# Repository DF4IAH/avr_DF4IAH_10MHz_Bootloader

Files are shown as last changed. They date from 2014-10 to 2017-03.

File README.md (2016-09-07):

# avr_DF4IAH_Bootloader

## GPS disciplined 10 MHz reference oscillator based on a (VC)TCXO
The project name for this device is __10 MHz-Ref.-Osc. V2.x__

That board is attached at the USB bus and receives power and does communication over it.
An optional LCD module can be connected to the I²C compatible bus for a stand-alone operation.

The author is Ulrich Habel (DF4IAH) with the idea having a low-cost and low-power device for a module to generate a 10 MHz signal at 3.3V TTL, that is adjusted to the GPS/Glonass satellite clock system. By this the local clock is kept in its boundaries to satisfy the long-term stability of the GPS/Glonass system. The negative aspect on it (I want to inform, also) with the use of a low power consuming VC-TCXO is, that the short-term variance is much higher than the variance of the devices using a temperature controlled oscillator like a rubidium lightwave controlled one.

### Contents of this repository
- __AVR ATmega 328P__: MPU containing a bootloader for programming the firmware itself via the USB interface by emulating an USBasp device 

- __Lattice LC4032V__: CPLD for containing a phase detection unit - source and binary

- __Eagle drawings__: oscillator and LCD - the schematics and boards for all variants of V2.x

### Additional information
The idea behind that project was to craft a local oscillator being in phase of the GPS clock system.
The device shall have a frequency and phase locked loop.
When the local frequency is trimmed to be equal to the reference GPS clock the phase locked loop gets in place of the frequency control.
Whenever the phase gets out of the secured boundaries, the system switches back to the frequency correction mode.
Due to its nature the device has to keep itself earnestly in the secured boundaries.
Only then the high quality stability of the GPS clock system can be delivered to the user.
For this reason when the local clock gets more out of balance and to one of its boundaries, a phase correction impulse is added to the local system to find the balance, again.
When still running a longer time this pulses are fine grained and the performance is very well for the user.
On the other hand when the GPS signals are poor, the almanac data old or the temperature variance at the VC-TCXO increasing, that local error-signal has to be corrected sometimes with sharp corrections.
So be warned to keep the device running in an air-locked container and a good GPS antenna position is a __must__ to get good results.

There are three different kinds of GPS units used by this project.
Each of them are utilizing the __MediaTek MT3333__ chipset, but each of the manufacturer is running its own configuration on it.
By this, some minor differences occur.
All of this GPS devices are able to track on GPS (western satellites) and Glonass/BeiDou (eastern satellites) signals.
Later at the works the author found out that the parallel processing of GPS and Glonass can result to interrupted functionality.
With NMEA programming the GPS device receives the command to ignore the Glonass signals but not all of them do honor that and start up tracking of all received signals.
The only work-around for this is to use a more selective GPS-antenna that filters out the Glonass signals away from the single GPS frequency.

The author has his reference clocks running for month without any problems, the firmware is stable - __use on your own risk, only!__

If you find this project nice you are welcomed to clone from it and run your optimizations or having a start point for a fresh project.

Any new modifications may result to harm this behavior.
Make your own decisions, be warned.

### Credits
I like to thank these following programmers and groups:

- __VUSB__ This code helped me to have USB communication on an ATmega, that does not support USB communication on its own.
All is done by interrupt software, many parts are assembly language based code.
Due to this nature all code in the bootloader as well as the firmware are very sensitive to changes on the code.
Only a very short interrupt time is allowed for the firmware avoiding the USB communication to fade out.
Find more about it: https://www.obdev.at/products/vusb/index.html

- __Wouter van Ooijen__ That person has reserved a valid USB address to be used by the community.
I like to thank him, that I am a part of this open source development community.

- __USBasp__ The base idea of the circuit is a reflection of this AVR programmer device.
The clou of it, it can communicate at the USB bus by itself: http://www.fischl.de/usbasp/

- __avrdude__ The bootloader code of avrdude gave ideas how to set-up a USB communication server.
The avrdude software can be found there: http://www.nongnu.org/avrdude/

- __HF-Messzwerg__ When the author got in contact with the team of this device, he started to learn about SMD soldering and USB communication in relation with an ATmega.
Communication is done with the help of an USB/serial converter.
More about that project can be found there: http://ukw-tagung.org/2016/preistraeger-2/

I wish you a nice experience with this product.
Fell free and enjoy it.

Cheers

Ulrich Habel  (DF4IAH)

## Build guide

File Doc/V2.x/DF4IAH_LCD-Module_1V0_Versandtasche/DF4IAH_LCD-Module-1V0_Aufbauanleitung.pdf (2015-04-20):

Aubauanleitung
DF4IAH LCD-Module V1.0

DF4IAH, Ulrich Habel

2015-04-18

Received | ; | accepted

– 2 –

### 1. Funktionsweise der Schaltung

Von Conrad und anderen Elektronik-Lieferanten sind LCD-Module erhältlich, die zwei

Textzeilen zu je 16 Zeichen bieten. Sie sind für elektronische Anwendungen sehr attraktiv.

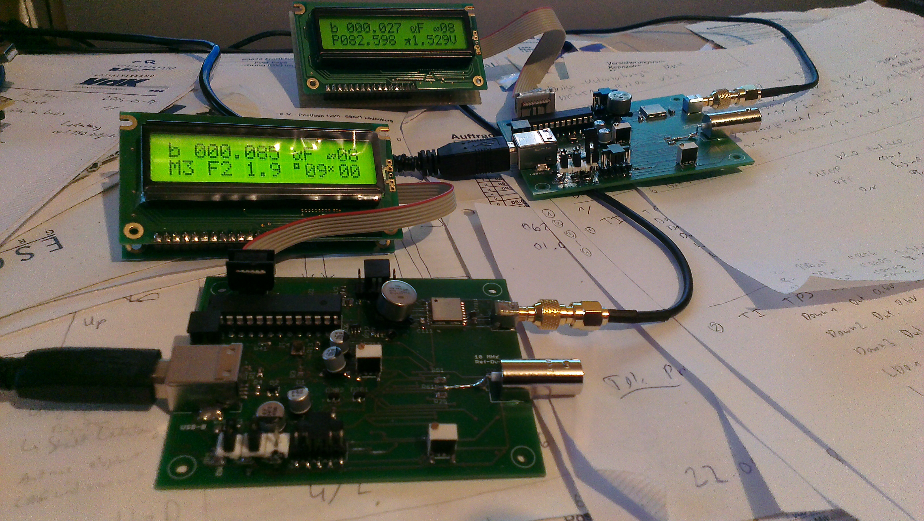
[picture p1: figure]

Fig. 1.— 2x16 LCD-Module in Betrieb

Angeschlossen werden diese über eine Parallelschnittstelle, die bereits eine Vielzahl

von freien I/O-Kanälen eines anzuschließenden µControllers belegen würden. Auf der

anderen Seite bieten solche µController meist auch eine I²C-Schnittstelle an. Die vorliegen-

de Schaltung setzt zwischen einem I²C-Bus und den parallelen Signalen am LCD-Module um.

– 3 –

Hier zunächst der Schaltplan:

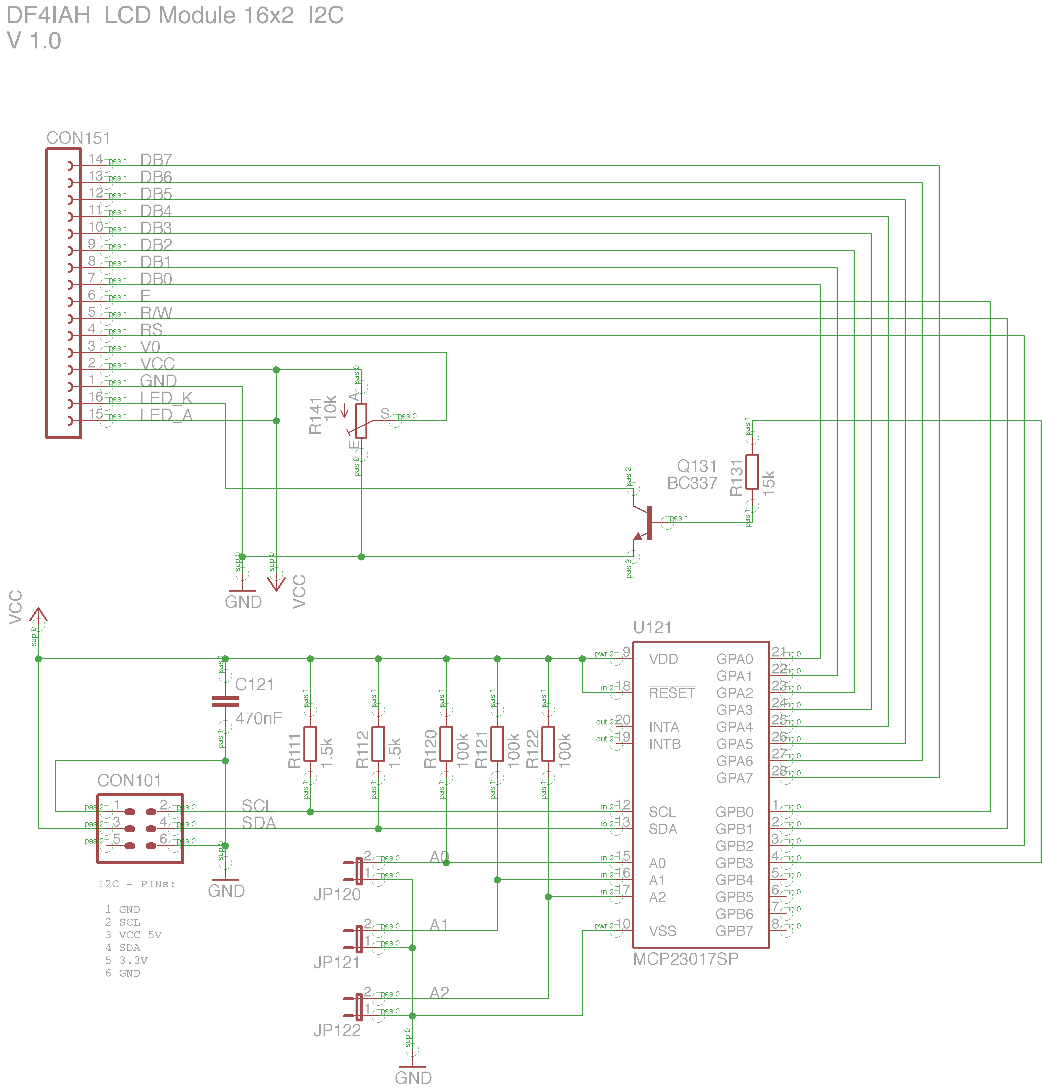
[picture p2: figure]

Fig. 2.— Schaltplan

– 4 –

Über den Steckkontakt CON101 wird die Betriebsspannung von 5.0 V zugeführt. Die

3.3 V wird nicht benötigt, sie ist aus Kompatibilitätsgründen nur aufgeführt. Der I²C-Bus

enthält neben dem obligatorischen Masse-Signal die beiden Signale SCL (Clock) und SDA

(Datentransport). Der I²C-Bus wird hier terminiert. Sollte bereits eine Bus-Terminierung

vorhanden sein, dann sollen die beiden Widerstände R111 und R112 nicht bestückt werden.

Als Port-Expander dient der U121, ein MCP23017 Baustein, der 2x 8 Bit I/Os zur Verfügung

stellt. Über die I²C-Schnittstelle wird dieses IC angesprochen. Mit den drei Jumper-Brücken

JP120 (A0), JP121 (A1) und JP122 (A2) wird die I²C-Adresse des Port-Expanders

ausgewählt. Somit wären bis zu acht solcher Displays an einem I²C-Bus betreibbar.

Zusätzlich wird über einen I/O-Pin die Hintergrundbeleuchtung des LCD-Moduls aktiviert.

Hierzu dient ein NPN-Transistor, dessen Basis-Strom über R131 begrenzt wird. Durch die

Stromverstärkung von ca. 350 ergibt sich ein für die Hintergrundbeleuchtung akzeptabler

Strom.

Die Datasheets zu dem LCD-Modul und MCP23017 werden entweder per E-Mail

weitergereicht, können aber auch von Conrad oder anderen Elektronik-Lieferanten

heruntergeladen werden.

### 2. Aufbau der Schaltung

Zunächst die LCD-Anzeige entpacken und sich mit der Geometrie der Bausatzleiterplatte

vertraut machen. Die Stiftleiste wird rückseitig in die LCD-Anzeige eingelötet. Somit

wird der breite Datenbus zur Bausatzplatine geführt. Die Bausatzplatine erhält eine

Buchsenleiste, welche dort eingelötet wird und steht dann links von der Schrift “CON151”.

Zur Kontrolle müssen die LCD-Anzeige auf die Bausatzplatine steck- und lösbar sein.

– 5 –

Vor jedem Lötvorgang empfehle ich zusätzlich Lötflussmittel, als Stiftform leicht an-

zuwenden, dieses zu verwenden. Es erleichtert das Löten mit SMD ganz wesentlich. Weiter

geht es mit dem Auflöten des IC-Sockels, dabei die Ausrichtung der Kerbe beachten, so

dass Sockel und später auch das IC selbst mit der Kerbe an der Stirnseite übereinander

ausgerichtet sind. Auf die gleiche Vorderseite kommt dann auch noch der Transistor, der wie

aufgedruckt ausgerichtet wird. Je nach Transistor-Gehäusebauform kann es nötig sein, den

mittleren Pin (Basis) etwas abzubiegen damit dieser in die zugehörige Anschluss-Bohrung

passt.

Die übrigen Bauteile auf dieser Oberseite („Top“) sind in der SMD-Bauform 0805. Dazu

empfiehlt es sich zuerst ein Pad etwas zu verzinnen, so dass eine kleine Lötkugel darauf

entsteht. So kann man bereits alle diese Pads einseitig vorbereiten. Im zweiten Schritt wird

das entsprechende Bauteil längs nach über die Platinenoberfläche geschoben, bis eine Seite

des SMD-Bausteins in das flüssige Lot eintaucht. Der Blick sollte dabei senkrecht von oben

durch eine Lupenleuchte erfolgen - so habe ich bisher die besten Resultate erzielt. Im dritten

Schritt wird dann das noch nicht benetzte Bauteilende mit dem noch unvorbereiteten Pad

verlötet. Optional kann im vierten Schritt zusätzlich Flussmittel aufgebracht werden und

die Lötspitze für einen ganz kurzen Moment jeweils an die SMD-Enden angetippt werden,

dadurch entsteht eine schöne, glänzende Lötstelle.

Auf der Rückseite der Leiterplatte („Bot“) werden zunächst die zweipoligen Stiftpaare

eingelötet. Dazu empfehle ich, nach dem Einsetzen der drei Stiftleisten einen Stecker darauf

zu stecken, damit die Stifte gerade stehen, wenn diese eingelötet werden. Die Stifte sind als

Durchsteckmontage vorgesehen, daher sollte das Anlöten recht leicht klappen. Bitte immer

die jeweilige Stiftleiste abkühlen lassen und besser erst mit der nächsten nebenan beginnen,

– 6 –

bevor der zweite Kontakt verlötet wird - sonst kann der Kunststoff weich werden und die

Stifte stünden dann nicht mehr gerade aufgerichtet.

Danach kommt noch die sechspolige Stiftleiste als SMD-Bauteil: auch hier wird zuerst ein

Lötpunkt gesetzt, vorzugsweise am Rand. Danach wird das Bauteil in das heiße Lötzinn

eingeschoben, dabei gerade ausrichten. Nun folgen die restlichen Anschlüsse. Auch hier

kann Flussmittel die Bearbeitung stark vereinfachen.

Nun kommt der Poti dran, der ebenfalls auf diese Rückseite gelötet wird. Die Voreinstel-

lung des Potis ist kurz vor dem Rechtsanschlag. Hilfe: wenn ich einen Lautstärkeregler

hochdrehe, dann drehe ich rechts herum. Genau in diese Richtung den R141 fast auf

Vollanschlag drehen. Nun ist die Leiterplatte bestückt, nach Belieben kann diese mit Steh-

bolzen mit der LCD-Anzeige verbunden und somit für ein Gehäuseeinbau vorbereitet werden.

Der letzte Schritt des Aufbaus dreht sich um das Flachbandkabel. Dieses wird zuerst

vorbereitet, indem das Kabel auf die benötige Länge gekürzt wird. Dann werden zwei nicht

benötigte und nicht farbig markierte Leitungen von dem Flachbandkabel entfernt,

damit die sechs restlichen Adern mit den Steckerenden verpresst werden können. Nun

kommen noch diese doppelreihigen Stiftleisten an die beiden Enden des Flachbandkabels

hinzu. Bitte die Ausrichtung beachten:

1. Der Press-Stecker wird derart auf die I²C-Stiftleiste aufgesetzt, dass die Nase des

Steckers von der Platine weg zeigt. Somit steht diese Nase knapp über dem Schriftzug

„I²C“.

2. Das Flachbandkabel wird derart in den Press-Stecker eingeschoben, dass die farbige

Ader des Flachbandkabels auf der Seite mit dem Schriftzug „1“ und „2“ ist.

– 7 –

3. Der zweite Press-Stecker wird in gleicher Ausrichtung montiert, die Nase zeigt somit

vom Kabel weg. Diese Seite wird auf dem 10 MHz-RefClk-Board enden und somit das

Kabel von dessen Platine wegführen.

Nachführend eine Abbildung der Kabelführung.

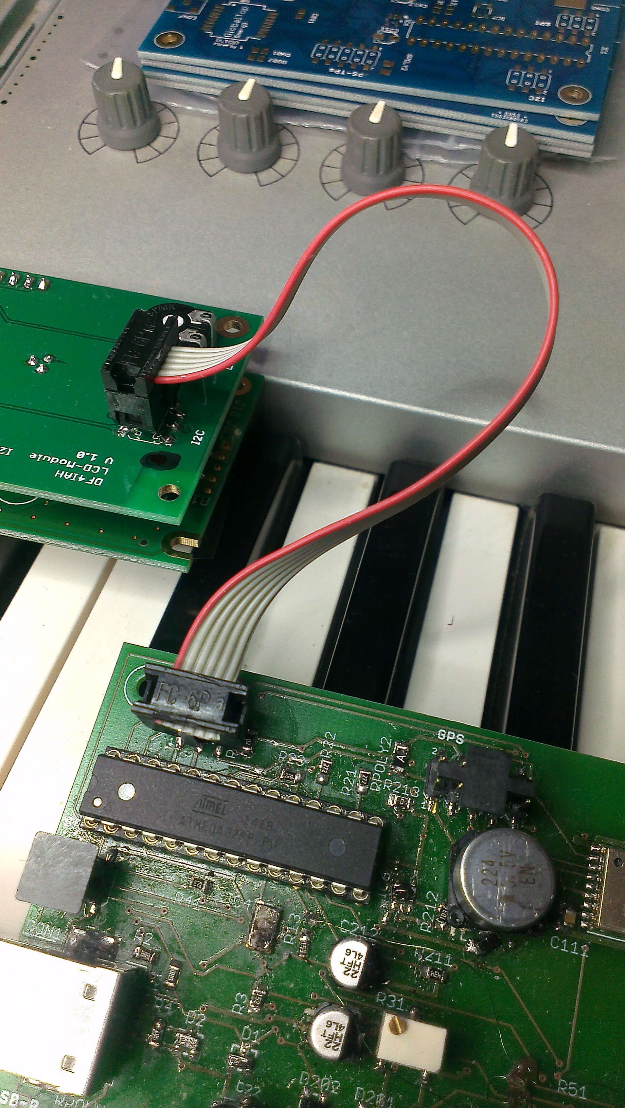
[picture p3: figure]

Fig. 3.— I²C-Kabelführung

Somit ist der Aufbau beendet.

– 8 –

### 3. Funktionstest

Nach dem Aufbau kann nun die Funktion getestet werden:

- Wer ein 10 MHz-RefClk-Modul hat, kann wie auf Abbildung 3 dieses mit der

Anzeige-Einheit verbinden. Wird nun der USB-Anschluss verbunden, so initialisiert

der Prozessor die Display-Einheit. Dieser schaltet das Backlight an (wenn nicht bereits

umkonfiguriert wurde) und begrüßt mit einem Initialisierungs-Schirm. Nun kann am

Poti R141 eine Feineinstellung des Display-Kontrasts vorgenommen werden.

- Wer kein 10 MHz-RefClk-Modul hat, kann die 5V-Anschlussleitung aktivieren - dabei

den Strom auf max. 100 mA begrenzen. Es sollte dann auf dem Display eine dunkle

Textzeile erscheinen, die zweite Zeile jedoch hell bleiben, den Kontrast mit dem Poti

nachregeln. Somit ist die Grundkonfiguration des LCD-Kontrastreglers gemacht. Die

Stromaufnahme liegt bei rund 20 mA und die Hintergrundbeleuchtung ist aus.

Diese Dokumentation erklärt nicht die nötige Programmierung eines µControllers zur

Ansteuerung des Displays, aber die Datasheets für die LCD-Anzeige und dem Port-Expander

genügen, um daraus ein funktionierendes Displaysystem zu machen. Hier noch ein paar

Punkte, die ich empfehlen würde:

- Die Vorgehensweise des LCD-Display zur Initialisierung wiederholt ein paar

Initialisierungsschritte mehrfach. Ich empfehle genau nach Spezifikation vorzugehen

um ein sicheres Anstarten des Moduls zu gewährleisten.

- Zum Eintakten eines Datenbytes benötigt man mehrere Zwischenschritte. Zuerst das

neue Byte setzen, danach das Datenbyte mit dem Clocksignal versehen und erneut

senden, dann wieder ohne dieses Clocksignal. Somit ist ein sicherer Byte-Transport

sichergestellt.

– 9 –

- Eine Applikations-Software würde hier vierschichtig sein:

– Zuerst eine Applikation, die das Display beschreibt (oder auch abfrägt),

– dann ein Modul, welches eine I²C-Transportschicht für den µController bereit

stellt (die dabei benutzte I²C-Clock-Frequenz beträgt 400 kHz und entspricht

der Norm für diesen Bus),

– dann ein Modul, welches die Initialisierung und die Bedienung des MCP23017

vornimmt,

– zuletzt ein Modul, welches die Intialisierung und die Bedienung der LCD-Anzeige

vornimmt

Bei dem Aufbau wünsche ich viel Erfolg. Bei evtl. Problemen bitte ich darum, mich zu

kontaktieren, damit wir dann eine Lösung finden.

Vy 73

Uli, DF4IAH

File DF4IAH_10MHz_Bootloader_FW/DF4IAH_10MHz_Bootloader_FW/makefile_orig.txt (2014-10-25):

# Hey Emacs, this is a -*- makefile -*-
#
# Makefile for the AVRProg-compatible Bootloader
#
# based on the 
# WinAVR Sample makefile written by Eric B. Weddington, J�rg Wunsch, et al.
# Released to the Public Domain
# Please read the make user manual!
#
# Additional material for this makefile was submitted by:
#  Tim Henigan
#  Peter Fleury
#  Reiner Patommel
#  Sander Pool
#  Frederik Rouleau
#  Markus Pfaff
#
# On command line:
#
# make all = Make software.
#
# make clean = Clean out built project files.
#
# make coff = Convert ELF to AVR COFF (for use with AVR Studio 3.x or VMLAB).
#
# make extcoff = Convert ELF to AVR Extended COFF (for use with AVR Studio
#                4.07 or greater).
#
# make program = Download the hex file to the device, using avrdude.  Please
#                customize the avrdude settings below first!
#
# make filename.s = Just compile filename.c into the assembler code only
#
# To rebuild project do "make clean" then "make all".
#

# user defined values

# MCU name
## MCU = atmega8
## MCU = atmega16
## MCU = atmega162
## MCU = atmega169
MCU = atmega32
## MCU = atmega324p
## MCU = atmega64
## MCU = atmega644
## MCU = atmega644p
## MCU = atmega128
## MCU = at90can128

################## BOOTLOADER ######################
#  mt: Boot loader support. So far not done with a separate section
#  to get the interrupt vector into the bootloader area (for BOOTINTVEC=yes).
#  Bootloader address in datasheet and stk500 is given as
#  "word", gcc toolchain needs "byte"-address
#  (see LDFLAGS further down)

#/* Select Boot Size in Words (select one, comment out the others) */
## NO! BOOTSIZE=128
## NO! BOOTSIZE=256
## BOOTSIZE=512
BOOTSIZE=1024
## BOOTSIZE=2048

# /* Select if bootloader should include the inverrupt-vectors 
# when selecting 'no' here, the bootloader must not use
# any interrupts and the modified linker-scripts are used. */
##BOOTINTVEC=yes
BOOTINTVEC=no

##
ifeq ($(MCU), atmega8)
BFD_MACH=avr4
ifeq ($(BOOTSIZE), 128)
	MT_BOOTLOADER_ADDRESS = 0x1F00
endif
ifeq ($(BOOTSIZE), 256)
	MT_BOOTLOADER_ADDRESS = 0x1E00
endif
ifeq ($(BOOTSIZE), 512)
	MT_BOOTLOADER_ADDRESS = 0x1C00
endif
ifeq ($(BOOTSIZE), 1024)
	MT_BOOTLOADER_ADDRESS = 0x1800
endif
endif

##
ifeq ($(MCU), atmega16)
BFD_MACH=avr5
ifeq ($(BOOTSIZE), 128)
	MT_BOOTLOADER_ADDRESS = 0x3F00
endif
ifeq ($(BOOTSIZE), 256)
	MT_BOOTLOADER_ADDRESS = 0x3E00
endif
ifeq ($(BOOTSIZE), 512)
	MT_BOOTLOADER_ADDRESS = 0x3C00
endif
ifeq ($(BOOTSIZE), 1024)
	MT_BOOTLOADER_ADDRESS = 0x3800
endif
endif

##
ifeq ($(MCU), atmega162)
BFD_MACH=avr5
ifeq ($(BOOTSIZE), 128)
	MT_BOOTLOADER_ADDRESS = 0x3F00
endif
ifeq ($(BOOTSIZE), 256)
	MT_BOOTLOADER_ADDRESS = 0x3E00
endif
ifeq ($(BOOTSIZE), 512)
	MT_BOOTLOADER_ADDRESS = 0x3C00
endif
ifeq ($(BOOTSIZE), 1024)
	MT_BOOTLOADER_ADDRESS = 0x3800
endif
endif

##
ifeq ($(MCU), atmega169)
BFD_MACH=avr5
ifeq ($(BOOTSIZE), 128)
	MT_BOOTLOADER_ADDRESS = 0x3F00
endif
ifeq ($(BOOTSIZE), 256)
	MT_BOOTLOADER_ADDRESS = 0x3E00
endif
ifeq ($(BOOTSIZE), 512)
	MT_BOOTLOADER_ADDRESS = 0x3C00
endif
ifeq ($(BOOTSIZE), 1024)
	MT_BOOTLOADER_ADDRESS = 0x3800
endif
endif

##
ifeq ($(MCU), atmega32)
BFD_MACH=avr5
ifeq ($(BOOTSIZE), 256)
	MT_BOOTLOADER_ADDRESS = 0x7E00
endif
ifeq ($(BOOTSIZE), 512)
	MT_BOOTLOADER_ADDRESS = 0x7C00
endif
ifeq ($(BOOTSIZE), 1024)
	MT_BOOTLOADER_ADDRESS = 0x7800
endif
ifeq ($(BOOTSIZE), 2048)
	MT_BOOTLOADER_ADDRESS = 0x7000
endif
endif

##
ifeq ($(MCU), atmega324p)
BFD_MACH=avr5
ifeq ($(BOOTSIZE), 256)
	MT_BOOTLOADER_ADDRESS = 0x7E00
endif
ifeq ($(BOOTSIZE), 512)
	MT_BOOTLOADER_ADDRESS = 0x7C00
endif
ifeq ($(BOOTSIZE), 1024)
	MT_BOOTLOADER_ADDRESS = 0x7800
endif
ifeq ($(BOOTSIZE), 2048)
	MT_BOOTLOADER_ADDRESS = 0x7000
endif
endif

##
ifeq ($(MCU), atmega64)
BFD_MACH=avr5
ifeq ($(BOOTSIZE), 512)
	MT_BOOTLOADER_ADDRESS = 0xFC00
endif
ifeq ($(BOOTSIZE), 1024)
	MT_BOOTLOADER_ADDRESS = 0xF800
endif
ifeq ($(BOOTSIZE), 2048)
	MT_BOOTLOADER_ADDRESS = 0xF000
endif
ifeq ($(BOOTSIZE), 4096)
	MT_BOOTLOADER_ADDRESS = 0xE000
endif
endif

##
ifeq ($(MCU), atmega644)
BFD_MACH=avr5
ifeq ($(BOOTSIZE), 512)
	MT_BOOTLOADER_ADDRESS = 0xFC00
endif
ifeq ($(BOOTSIZE), 1024)
	MT_BOOTLOADER_ADDRESS = 0xF800
endif
ifeq ($(BOOTSIZE), 2048)
	MT_BOOTLOADER_ADDRESS = 0xF000
endif
ifeq ($(BOOTSIZE), 4096)
	MT_BOOTLOADER_ADDRESS = 0xE000
endif
endif

##
ifeq ($(MCU), atmega644p)
BFD_MACH=avr5
ifeq ($(BOOTSIZE), 512)
	MT_BOOTLOADER_ADDRESS = 0xFC00
endif
ifeq ($(BOOTSIZE), 1024)
	MT_BOOTLOADER_ADDRESS = 0xF800
endif
ifeq ($(BOOTSIZE), 2048)
	MT_BOOTLOADER_ADDRESS = 0xF000
endif
ifeq ($(BOOTSIZE), 4096)
	MT_BOOTLOADER_ADDRESS = 0xE000
endif
endif

##
ifeq ($(MCU), atmega128)
BFD_MACH=avr5
ifeq ($(BOOTSIZE), 512)
	MT_BOOTLOADER_ADDRESS = 0x1FC00
endif
ifeq ($(BOOTSIZE), 1024)
	MT_BOOTLOADER_ADDRESS = 0x1F800
endif
ifeq ($(BOOTSIZE), 2048)
	MT_BOOTLOADER_ADDRESS = 0x1F000
endif
ifeq ($(BOOTSIZE), 4096)
	MT_BOOTLOADER_ADDRESS = 0x1E000
endif
endif

##
ifeq ($(MCU), at90can128)
BFD_MACH=avr5
ifeq ($(BOOTSIZE), 512)
	MT_BOOTLOADER_ADDRESS = 0x1FC00
endif
ifeq ($(BOOTSIZE), 1024)
	MT_BOOTLOADER_ADDRESS = 0x1F800
endif
ifeq ($(BOOTSIZE), 2048)
	MT_BOOTLOADER_ADDRESS = 0x1F000
endif
ifeq ($(BOOTSIZE), 4096)
	MT_BOOTLOADER_ADDRESS = 0x1E000
endif
endif

# Output format. (can be srec, ihex, binary)
FORMAT = ihex
#FORMAT = srec

# Target file name (without extension).
TARGET = main

# List C source files here. (C dependencies are automatically generated.)
SRC = $(TARGET).c

# List Assembler source files here.
# Make them always end in a capital .S.  Files ending in a lowercase .s
# will not be considered source files but generated files (assembler
# output from the compiler), and will be deleted upon "make clean"!
# Even though the DOS/Win* filesystem matches both .s and .S the same,
# it will preserve the spelling of the filenames, and gcc itself does
# care about how the name is spelled on its command-line.
ASRC =

# Optimization level, can be [0, 1, 2, 3, s].
# 0 = turn off optimization. s = optimize for size.
# (Note: 3 is not always the best optimization level. See avr-libc FAQ.)
OPT = s

# Debugging format.
# Native formats for AVR-GCC's -g are stabs [default], or dwarf-2.
# AVR (extended) COFF requires stabs, plus an avr-objcopy run.
DEBUG = stabs

# List any extra directories to look for include files here.
#     Each directory must be seperated by a space.
EXTRAINCDIRS =

# Compiler flag to set the C Standard level.
# c89   - "ANSI" C
# gnu89 - c89 plus GCC extensions
# c99   - ISO C99 standard (not yet fully implemented)
# gnu99 - c99 plus GCC extensions
CSTANDARD = -std=gnu99

# Place -D or -U options here
CDEFS = -DBOOTSIZE=$(BOOTSIZE)

# Place -I options here
CINCS =

# Compiler flags.
#  -g*:          generate debugging information
#  -O*:          optimization level
#  -f...:        tuning, see GCC manual and avr-libc documentation
#  -Wall...:     warning level
#  -Wa,...:      tell GCC to pass this to the assembler.
#    -adhlns...: create assembler listing
CFLAGS = -g$(DEBUG)
CFLAGS += $(CDEFS) $(CINCS)
CFLAGS += -O$(OPT)
CFLAGS += -funsigned-char -funsigned-bitfields -fpack-struct -fshort-enums
CFLAGS += -Wall -Wstrict-prototypes
CFLAGS += -Wa,-adhlns=$(<:.c=.lst)
CFLAGS += $(patsubst %,-I%,$(EXTRAINCDIRS))
CFLAGS += $(CSTANDARD)

# Assembler flags.
#  -Wa,...:   tell GCC to pass this to the assembler.
#  -ahlms:    create listing
#  -gstabs:   have the assembler create line number information; note that
#             for use in COFF files, additional information about filenames
#             and function names needs to be present in the assembler source
#             files -- see avr-libc docs [FIXME: not yet described there]
ASFLAGS = -Wa,-adhlns=$(<:.S=.lst),-gstabs

#Additional libraries.

# Minimalistic printf version
PRINTF_LIB_MIN = -Wl,-u,vfprintf -lprintf_min

# Floating point printf version (requires MATH_LIB = -lm below)
PRINTF_LIB_FLOAT = -Wl,-u,vfprintf -lprintf_flt

PRINTF_LIB =

# Minimalistic scanf version
SCANF_LIB_MIN = -Wl,-u,vfscanf -lscanf_min

# Floating point + %[ scanf version (requires MATH_LIB = -lm below)
SCANF_LIB_FLOAT = -Wl,-u,vfscanf -lscanf_flt

SCANF_LIB =

MATH_LIB = -lm

# External memory options

# 64 KB of external RAM, starting after internal RAM (ATmega128!),
# used for variables (.data/.bss) and heap (malloc()).
#EXTMEMOPTS = -Wl,-Tdata=0x801100,--defsym=__heap_end=0x80ffff

# 64 KB of external RAM, starting after internal RAM (ATmega128!),
# only used for heap (malloc()).
#EXTMEMOPTS = -Wl,--defsym=__heap_start=0x801100,--defsym=__heap_end=0x80ffff

EXTMEMOPTS =

# Linker flags.
#  -Wl,...:     tell GCC to pass this to linker.
#    -Map:      create map file
#    --cref:    add cross reference to  map file
LDFLAGS = -Wl,-Map=$(TARGET).map,--cref
LDFLAGS += $(EXTMEMOPTS)
LDFLAGS += $(PRINTF_LIB) $(SCANF_LIB) $(MATH_LIB)

################## BOOTLOADER ######################
# MT_BOOTLOADER_ADDRESS (=Start of Boot Loader section
# in bytes - not words) as defined above.
LDFLAGS += -Wl,--section-start=.text=$(MT_BOOTLOADER_ADDRESS)

# check if linker-scripts without interrupt-vectors should
# be used and set linker-option, announce to C-code by define
ifeq ($(BOOTINTVEC), no)
LDFLAGS += -T./ldscripts_no_vector/$(BFD_MACH).x
CFLAGS  += -DBOOTLOADERHASNOVECTORS
endif

# Programming support using avrdude. Settings and variables.

# Programming hardware: alf avr910 avrisp bascom bsd
# dt006 pavr picoweb pony-stk200 sp12 stk200 stk500
#
# Type: avrdude -c ?
# to get a full listing.
#
AVRDUDE_PROGRAMMER = stk500v2

# com1 = serial port. Use lpt1 to connect to parallel port.
AVRDUDE_PORT = com1    # programmer connected to serial device
#AVRDUDE_PORT = /dev/ttyS0    # programmer connected to serial device

AVRDUDE_WRITE_FLASH = -U flash:w:$(TARGET).hex
#AVRDUDE_WRITE_EEPROM = -U eeprom:w:$(TARGET).eep

# Uncomment the following if you want avrdude's erase cycle counter.
# Note that this counter needs to be initialized first using -Yn,
# see avrdude manual.
#AVRDUDE_ERASE_COUNTER = -y

# Uncomment the following if you do /not/ wish a verification to be
# performed after programming the device.
#AVRDUDE_NO_VERIFY = -V

# Increase verbosity level.  Please use this when submitting bug
# reports about avrdude. See <http://savannah.nongnu.org/projects/avrdude>
# to submit bug reports.
#AVRDUDE_VERBOSE = -v -v

AVRDUDE_FLAGS = -p $(MCU) -P $(AVRDUDE_PORT) -c $(AVRDUDE_PROGRAMMER)
AVRDUDE_FLAGS += $(AVRDUDE_NO_VERIFY)
AVRDUDE_FLAGS += $(AVRDUDE_VERBOSE)
AVRDUDE_FLAGS += $(AVRDUDE_ERASE_COUNTER)

# ---------------------------------------------------------------------------

# Define directories, if needed.
#DIRAVR = c:/winavr
#DIRAVRBIN = $(DIRAVR)/bin
#DIRAVRUTILS = $(DIRAVR)/utils/bin
#DIRINC = .
#DIRLIB = $(DIRAVR)/avr/lib

# Define programs and commands.
#SHELL = $(DIRAVRUTILS)/sh
#NM = $(DIRAVRBIN)/avr-nm
#CC = $(DIRAVRBIN)/avr-gcc
#OBJCOPY = $(DIRAVRBIN)/avr-objcopy
#OBJDUMP= $(DIRAVRBIN)/avr-objdump
#SIZE = $(DIRAVRBIN)/avr-size
#AVRDUDE = $(DIRAVRBIN)/avrdude.sh
#REMOVE = rm -f
#COPY = cp

# Define programs and commands.
SHELL = sh
CC = avr-gcc
OBJCOPY = avr-objcopy
OBJDUMP = avr-objdump
SIZE = avr-size
NM = avr-nm
AVRDUDE = avrdude
REMOVE = rm -f
COPY = cp
WINSHELL = cmd

# Define Messages
# English
MSG_ERRORS_NONE = Errors: none
MSG_BEGIN = -------- begin --------
MSG_END = --------  end  --------
MSG_SIZE_BEFORE = Size before:
MSG_SIZE_AFTER = Size after:
MSG_COFF = Converting to AVR COFF:
MSG_EXTENDED_COFF = Converting to AVR Extended COFF:
MSG_FLASH = Creating load file for Flash:
MSG_EEPROM = Creating load file for EEPROM:
MSG_EXTENDED_LISTING = Creating Extended Listing:
MSG_SYMBOL_TABLE = Creating Symbol Table:
MSG_LINKING = Linking:
MSG_COMPILING = Compiling:
MSG_ASSEMBLING = Assembling:
MSG_CLEANING = Cleaning project:

# Define all object files.
OBJ = $(SRC:.c=.o) $(ASRC:.S=.o)

# Define all listing files.
LST = $(ASRC:.S=.lst) $(SRC:.c=.lst)

# Compiler flags to generate dependency files.
### GENDEPFLAGS = -Wp,-M,-MP,-MT,$(*F).o,-MF,.dep/$(@F).d
GENDEPFLAGS = -MD -MP -MF .dep/$(@F).d

# Combine all necessary flags and optional flags.
# Add target processor to flags.
ALL_CFLAGS = -mmcu=$(MCU) -I. $(CFLAGS) $(GENDEPFLAGS)
ALL_ASFLAGS = -mmcu=$(MCU) -I. -x assembler-with-cpp $(ASFLAGS)

# Default target.
all: begin gccversion sizebefore build sizeafter finished end

build: elf hex eep lss sym

elf: $(TARGET).elf
hex: $(TARGET).hex
eep: $(TARGET).eep
lss: $(TARGET).lss
sym: $(TARGET).sym

# Eye candy.
# AVR Studio 3.x does not check make's exit code but relies on
# the following magic strings to be generated by the compile job.
begin:
	@echo
	@echo $(MSG_BEGIN)

finished:
	@echo $(MSG_ERRORS_NONE)

end:
	@echo $(MSG_END)
	@echo

# Display size of file.
HEXSIZE = $(SIZE) --target=$(FORMAT) $(TARGET).hex
ELFSIZE = $(SIZE) -x -A $(TARGET).elf
sizebefore:
	@if [ -f $(TARGET).elf ]; then echo; echo $(MSG_SIZE_BEFORE); $(ELFSIZE); echo; fi

sizeafter:
	@if [ -f $(TARGET).elf ]; then echo; echo $(MSG_SIZE_AFTER); $(ELFSIZE); echo; fi

# Display compiler version information.
gccversion :
	@$(CC) --version

# Program the device.
program: $(TARGET).hex $(TARGET).eep
	$(AVRDUDE) $(AVRDUDE_FLAGS) $(AVRDUDE_WRITE_FLASH) $(AVRDUDE_WRITE_EEPROM)

# Convert ELF to COFF for use in debugging / simulating in AVR Studio or VMLAB.
COFFCONVERT=$(OBJCOPY) --debugging \
--change-section-address .data-0x800000 \
--change-section-address .bss-0x800000 \
--change-section-address .noinit-0x800000 \
--change-section-address .eeprom-0x810000

coff: $(TARGET).elf
	@echo
	@echo $(MSG_COFF) $(TARGET).cof
	$(COFFCONVERT) -O coff-avr $< $(TARGET).cof

extcoff: $(TARGET).elf
	@echo
	@echo $(MSG_EXTENDED_COFF) $(TARGET).cof
	$(COFFCONVERT) -O coff-ext-avr $< $(TARGET).cof

# Create final output files (.hex, .eep) from ELF output file.
%.hex: %.elf
	@echo
	@echo $(MSG_FLASH) $@
	$(OBJCOPY) -O $(FORMAT) -R .eeprom $< $@

%.eep: %.elf
	@echo
	@echo $(MSG_EEPROM) $@
	-$(OBJCOPY) -j .eeprom --set-section-flags=.eeprom="alloc,load" \
	--change-section-lma .eeprom=0 -O $(FORMAT) $< $@

# Create extended listing file from ELF output file.
%.lss: %.elf
	@echo
	@echo $(MSG_EXTENDED_LISTING) $@
	$(OBJDUMP) -h -S $< > $@

# Create a symbol table from ELF output file.
%.sym: %.elf
	@echo
	@echo $(MSG_SYMBOL_TABLE) $@
	$(NM) -n $< > $@

# Link: create ELF output file from object files.
.SECONDARY : $(TARGET).elf
.PRECIOUS : $(OBJ)
%.elf: $(OBJ)
	@echo
	@echo $(MSG_LINKING) $@
	$(CC) $(ALL_CFLAGS) $(OBJ) --output $@ $(LDFLAGS)

# Compile: create object files from C source files.
%.o : %.c
	@echo
	@echo $(MSG_COMPILING) $<
	$(CC) -c $(ALL_CFLAGS) $< -o $@

# Compile: create assembler files from C source files.
%.s : %.c
	$(CC) -S $(ALL_CFLAGS) $< -o $@

# Assemble: create object files from assembler source files.
%.o : %.S
	@echo
	@echo $(MSG_ASSEMBLING) $<
	$(CC) -c $(ALL_ASFLAGS) $< -o $@

# Target: clean project.
clean: begin clean_list finished end

clean_list :
	@echo
	@echo $(MSG_CLEANING)
	$(REMOVE) $(TARGET).hex
	$(REMOVE) $(TARGET).eep
	$(REMOVE) $(TARGET).obj
	$(REMOVE) $(TARGET).cof
	$(REMOVE) $(TARGET).elf
	$(REMOVE) $(TARGET).map
	$(REMOVE) $(TARGET).obj
	$(REMOVE) $(TARGET).a90
	$(REMOVE) $(TARGET).sym
	$(REMOVE) $(TARGET).lnk
	$(REMOVE) $(TARGET).lss
	$(REMOVE) $(OBJ)
	$(REMOVE) $(LST)
	$(REMOVE) $(SRC:.c=.s)
	$(REMOVE) $(SRC:.c=.d)
	$(REMOVE) .dep/*

# Include the dependency files.
-include $(shell mkdir .dep 2>/dev/null) $(wildcard .dep/*)

# Listing of phony targets.
.PHONY : all begin finish end sizebefore sizeafter gccversion \
build elf hex eep lss sym coff extcoff \
clean clean_list program

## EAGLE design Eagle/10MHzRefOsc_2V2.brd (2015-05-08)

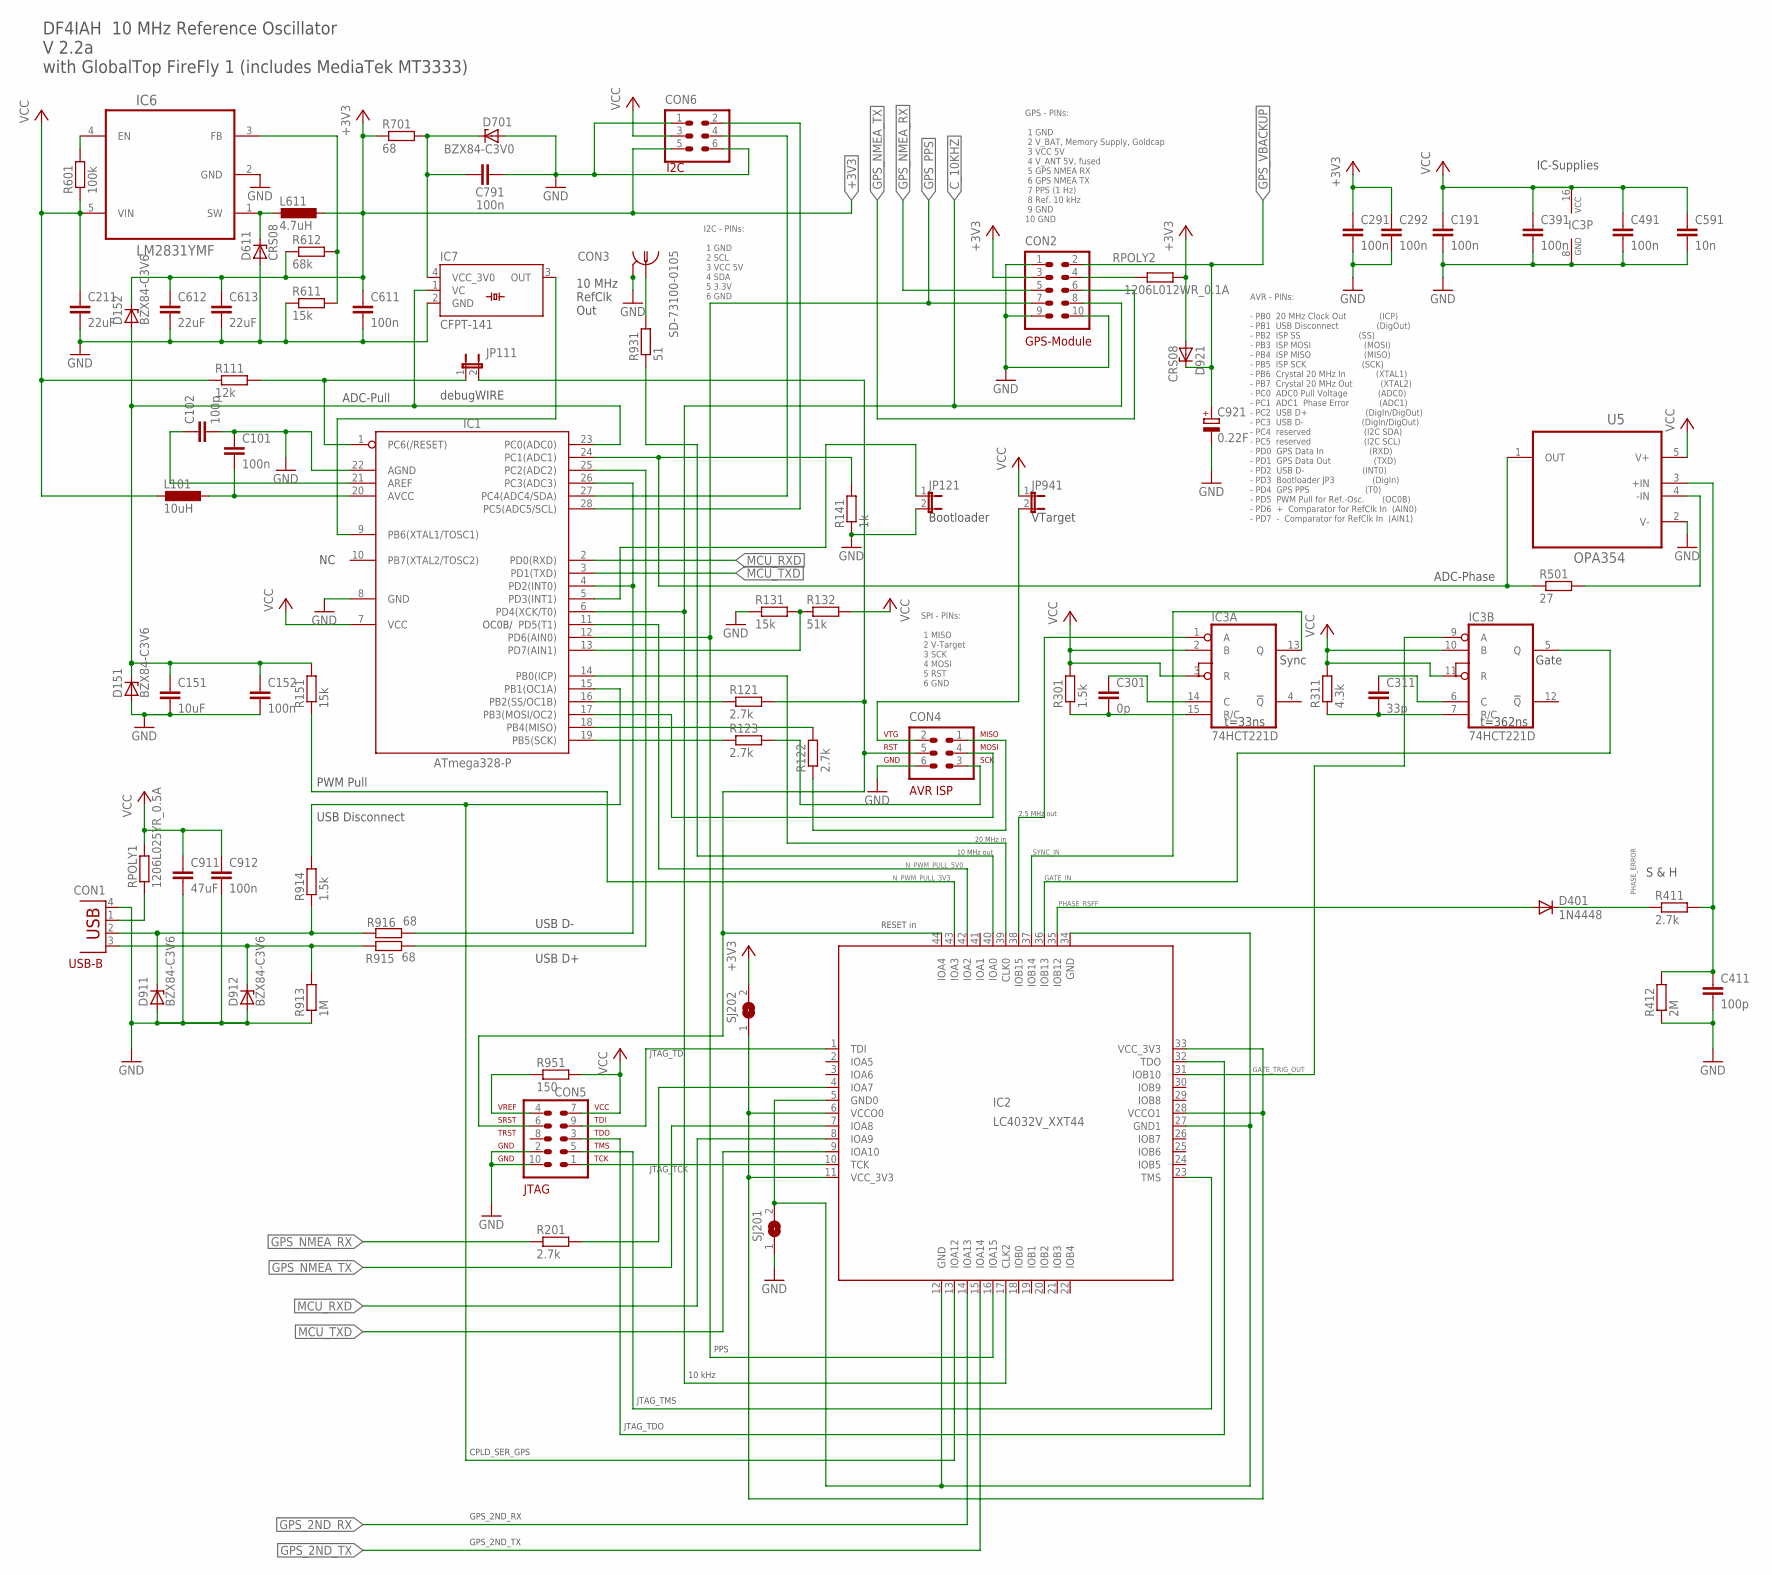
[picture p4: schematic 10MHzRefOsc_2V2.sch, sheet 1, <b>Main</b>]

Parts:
C101, C152, C191, C291, C292, C391, C491, C611, C791, C912: 100n; C0805
C102, C411: 100p; C0805
C151: 10uF; C0805
C211, C612, C613: 22uF; C0805
C301: 0p; C0805
C311: 33p; C0805
C591: 10n; C0805
C911: 47uF; C0805
C921: 0.22F; 140CLH-1010
CON1: TYCO-AMP_USBUSB-B_SMT; TYCO-AMP_USB-B_SMT
CON2: HEADER-2X5SMD; 2X5SMD
CON3: SD-73100-0105; MOLEX_BNC-JACK-50R_SD-73100-0105
CON4: AVR-ISP-6SMD; 2X3SMD
CON5: AVR-JTAG-10SMD; 2X5SMD
CON6: HEADER-2X3SMD; 2X03SMD
D151, D152, D911, D912: BZX84-C3V6; TO236
D401: 1N4448; SOD123
D611, D921: CRS08; SOD80C
D701: BZX84-C3V0; TO236
IC1: ATmega328-P; DIL28-3
IC2: LC4032V_XXT44; TQFP44
IC3: 74HCT221D; SO16
IC6: LM2831YMF; SOT95P280X145-5N
IC7: CFPT-141
JP111, JP121, JP941: JP1E; JP1
L101: 10uH; L1812
L611: 4.7uH; L5650M
R111: 12k; R0805
R121, R122, R123, R201, R411: 2.7k; R0805
R131, R151, R611: 15k; R0805
R132: 51k; R0805
R141: 1k; R0805
R301, R914: 1.5k; R0805
R311: 4.3k; R0805
R412: 2M; R0805
R501: 27; R0805
R601: 100k; R0805
R612: 68k; R0805
R701, R915, R916: 68; R0805
R913: 1M; R0805
R931: 51; R0805
R951: 150; R0805
RPOLY1: 1206L025YR_0.5A; M1206
RPOLY2: 1206L012WR_0.1A; M1206
SJ201, SJ202: SJ
U5: OPA354; SOT-23-5

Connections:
+3V0: C791.1, D701.C, IC7.4 (VCC_3V0), R701.2
+3V3: C291.1, C292.1, C611.1, C612.1, C613.1, CON2.3, CON6.5, D152.C, D921.A, L611.1, R612.1, R701.1, RPOLY2.2, SJ202.2
ADC_PHASE: IC1.24 (PC1(ADC1)), R141.2, R501.1, U5.1 (OUT)
ADC_PHASE_SAMPLEHOLD: C411.1, R411.2, R412.2, U5.3 (+IN)
AIN1: IC1.13 (PD7(AIN1)), R131.2, R132.1
AREF: C102.1, IC1.21 (AREF)
AVCC: C101.2, IC1.20 (AVCC), L101.1
CPLD_GPS_NMEA_RX: IC2.4 (IOA7), R201.2
C_2MHZ5: IC2.38 (IOB15), IC3.1 (A)
C_10KHZ: CON2.8, IC1.6 (PD4(XCK/T0)), IC2.17 (CLK2)
C_10MHZ: IC2.40 (IOA0), R931.1
C_20MHZ: IC1.14 (PB0(ICP)), IC2.39 (CLK0)
EN: IC6.4 (EN), R601.2
FB: IC6.3 (FB), R611.2, R612.2
GATE_IN: IC2.36 (IOB13), IC3.5 (Q)
GATE_TRIG_OUT: IC2.31 (IOB10), IC3.9 (A)
GND: C101.1, C102.2, C151.2, C152.2, C191.2, C211.2, C291.2, C292.2, C391.2, C411.2, C491.2, C591.2, C611.2, C612.2, C613.2, C791.2, C911.2, C912.2, C921.-, CON1.4 (GND), CON2.1, CON2.9, CON2.10, CON3.2, CON3.3, CON4.6, CON5.2, CON5.10, CON6.1, CON6.6, D151.A, D611.A, D701.A, D911.A, D912.A, IC1.8 (GND), IC1.22 (AGND), IC3.8 (GND), IC6.2 (GND), IC7.2 (GND), JP121.2, R131.1, R141.1, R412.1, R611.1, R913.1, SJ201.1, U5.2 (V-); also elsewhere on the board
GND_SJ1: IC2.5 (GND0), IC2.12 (GND), IC2.27 (GND1), IC2.34 (GND), SJ201.2
GPS_2ND_RX: IC2.14 (IOA13); also elsewhere on the board
GPS_2ND_TX: IC2.15 (IOA14); also elsewhere on the board
GPS_ANT_PWR: CON2.4, RPOLY2.1; also elsewhere on the board
GPS_NMEA_RX: CON2.5, R201.1; also elsewhere on the board
GPS_NMEA_TX: CON2.6, IC2.7 (IOA8); also elsewhere on the board
GPS_PPS: CON2.7, IC1.12 (PD6(AIN0)), IC2.16 (IOA15); also elsewhere on the board
GPS_VBACKUP: C921.+, CON2.2, D921.C; also elsewhere on the board
INT1: IC1.5 (PD3(INT1)), JP121.1
ISP_MISO: CON4.1, R122.1
ISP_MOSI: CON4.4, IC1.17 (PB3(MOSI/OC2))
ISP_SCK: CON4.3, R123.2
ISP_VTARGET: CON4.2, JP941.2
JTAG_SRST: CON4.5, CON5.6, IC2.44 (IOA4), JP111.2, R121.2
JTAG_TCK: CON5.1, IC2.10 (TCK)
JTAG_TDI: CON5.9, IC2.1 (TDI)
JTAG_TDO: CON5.3, IC2.32 (TDO)
JTAG_TMS: CON5.5, IC2.23 (TMS)
JTAG_VREF: CON5.4, R951.1
MCU_RXD: IC1.2 (PD0(RXD)), IC2.8 (IOA9)
MCU_TXD: IC1.3 (PD1(TXD)), IC2.9 (IOA10)
MISO: IC1.18 (PB4(MISO)), R122.2
unnamed: CON6.2, IC1.28 (PC5(ADC5/SCL))
unnamed: CON6.4, IC1.27 (PC4(ADC4/SDA))
unnamed: CON3.1, R931.2
unnamed: C311.2, IC3.7 (R/C), R311.1
unnamed: C311.1, IC3.6 (C)
unnamed: C301.2, IC3.15 (R/C), R301.1
unnamed: C301.1, IC3.14 (C)
N_ADC_PULL: C151.1, C152.1, D151.C, D152.A, IC1.23 (PC0(ADC0)), IC7.1 (VC), R151.2
N_PWM_PULL_3V3: IC2.43 (IOA3), R151.1
N_PWM_PULL_5V0: IC1.11 (PD5(T1)), IC2.42 (IOA2)
N_USB_DISC: IC1.15 (PB1(OC1A)), IC2.13 (IOA12), R914.2
N_USB_DMNS: IC1.4 (PD2(INT0)), IC1.26 (PC3(ADC3)), R916.2
N_USB_DPLS: IC1.25 (PC2(ADC2)), R915.2
PHASE_ERROR: D401.C, R411.1
PHASE_RSFF: D401.A, IC2.35 (IOB12)
RESET: IC1.1 (PC6(/RESET)), JP111.1, R111.2
SCK: IC1.19 (PB5(SCK)), R123.1
SS: IC1.16 (PB2(SS/OC1B)), R121.1
SW: D611.C, IC6.1 (SW), L611.2
SYNC_IN: IC2.37 (IOB14), IC3.13 (Q)
TOSC1: IC1.9 (PB6(XTAL1/TOSC1)), IC7.3 (OUT)
U5_FB: R501.2, U5.4 (-IN)
USB_D_MIN: CON1.2 (D-), D911.C, R914.1, R916.1
USB_D_PLS: CON1.3 (D+), D912.C, R913.2, R915.1
USB_PWR: CON1.1 (VBUS), RPOLY1.1
VCC: C191.1, C211.1, C391.1, C491.1, C591.1, C911.1, C912.1, CON5.7, CON6.3, IC1.7 (VCC), IC3.2 (B), IC3.3 (R), IC3.10 (B), IC3.11 (R), IC3.16 (VCC), IC6.5 (VIN), JP941.1, L101.2, R111.1, R132.2, R301.2, R311.2, R601.1, R951.2, RPOLY1.2, U5.5 (V+)
VCC_3V3_SJ2: IC2.6 (VCCO0), IC2.11 (VCC_3V3), IC2.28 (VCCO1), IC2.33 (VCC_3V3), SJ202.1

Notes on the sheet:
VTarget
debugWIRE
USB-B
AVR - PINs: - PB0 20 MHz Clock Out (ICP) - PB1 USB Disconnect (DigOut) - PB2 ISP SS (SS) - PB3 ISP MOSI (MOSI) - PB4 ISP MISO (MISO) - PB5 ISP SCK (SCK) - PB6 Crystal 20 MHz In (XTAL1) - PB7 Crystal 20 MHz Out (XTAL2) - PC0 ADC0 Pull Voltage (ADC0) - PC1 ADC1 Phase Error (ADC1) - PC2 USB D+ (DigIn/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
10 MHz RefClk Out
Bootloader
Gate
GPS-Module
GPS - PINs: 1 GND 2 V_BAT, Memory Supply, Goldcap 3 VCC 5V 4 V_ANT 5V, fused 5 GPS NMEA RX 6 GPS NMEA TX 7 PPS (1 Hz) 8 Ref. 10 kHz 9 GND 10 GND
S & H
ADC-Phase
PWM Pull
ADC-Pull
Sync
t=33ns
t=362ns
IC-Supplies
20 MHz in
10 MHz out
2.5 MHz out
DF4IAH 10 MHz Reference Oscillator V 2.2a with GlobalTop FireFly 1 (includes MediaTek MT3333)
USB Disconnect
USB D-
USB D+
SPI - PINs: 1 MISO 2 V-Target 3 SCK 4 MOSI 5 RST 6 GND
10 kHz
PPS
RESET in
JTAG_TMS
JTAG_TDO
JTAG_TCK
JTAG_TDI
CPLD_SER_GPS
I2C - PINs: 1 GND 2 SCL 3 VCC 5V 4 SDA 5 3.3V 6 GND
I2C
OC0B/
GPS_2ND_RX
GPS_2ND_TX

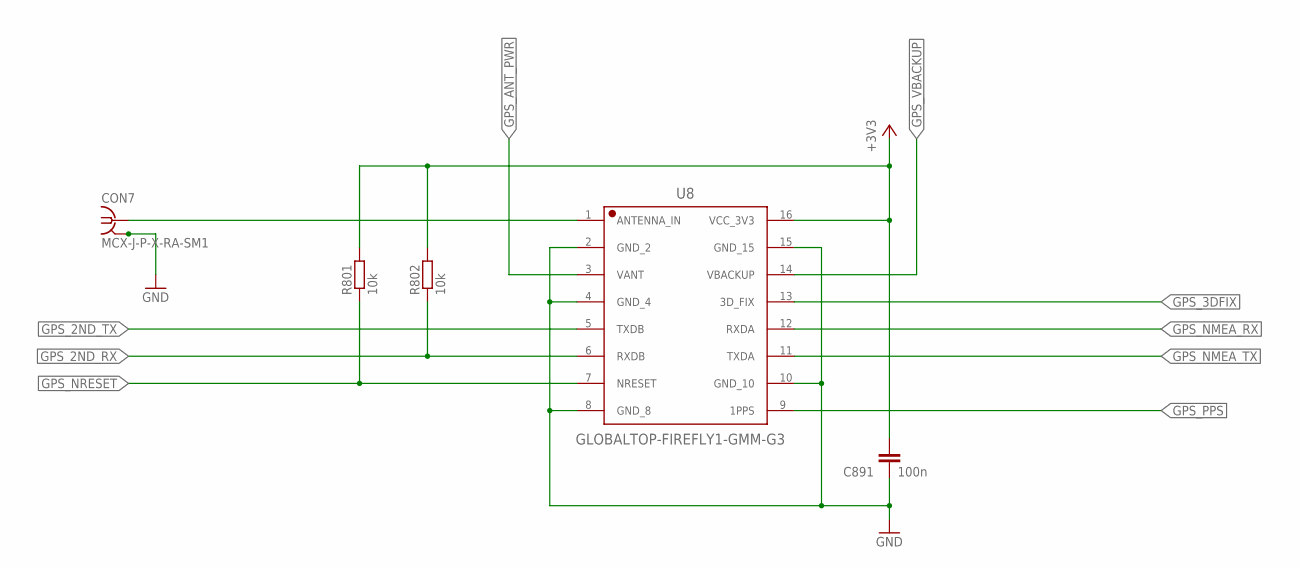
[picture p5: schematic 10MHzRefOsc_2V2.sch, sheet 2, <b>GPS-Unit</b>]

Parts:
C891: 100n; C0805
CON7: MCX-J-P-X-RA-SM1
R801, R802: 10k; R0805
U8: GLOBALTOP-FIREFLY1-GMM-G3

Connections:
GND: C891.2, CON7.2, CON7.3, CON7.4, CON7.5, U8.2 (GND_2), U8.4 (GND_4), U8.8 (GND_8), U8.10 (GND_10), U8.15 (GND_15); also elsewhere on the board
GPS_2ND_RX: R802.1, U8.6 (RXDB); also elsewhere on the board
GPS_2ND_TX: U8.5 (TXDB); also elsewhere on the board
GPS_3DFIX: U8.13 (3D_FIX)
GPS_ANT_PWR: U8.3 (VANT); also elsewhere on the board
GPS_NMEA_RX: U8.12 (RXDA); also elsewhere on the board
GPS_NMEA_TX: U8.11 (TXDA); also elsewhere on the board
GPS_NRESET: R801.1, U8.7 (NRESET)
GPS_PPS: U8.9 (1PPS); also elsewhere on the board
GPS_VBACKUP: U8.14 (VBACKUP); also elsewhere on the board
unnamed: CON7.1, U8.1 (ANTENNA_IN)
VCC_3V3: C891.1, R801.2, R802.2, U8.16 (VCC_3V3)

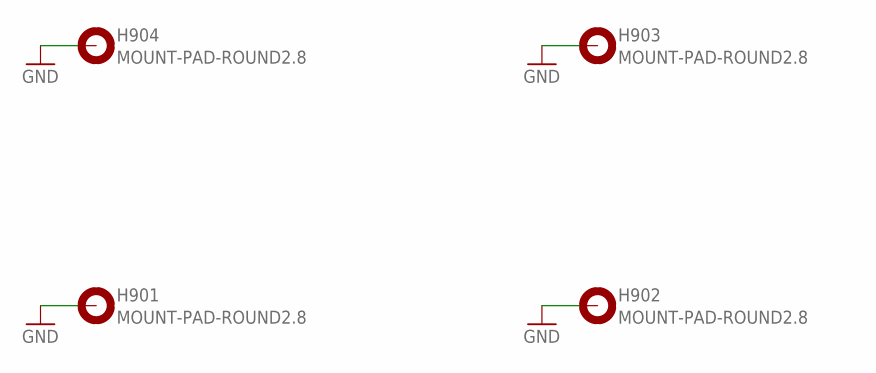
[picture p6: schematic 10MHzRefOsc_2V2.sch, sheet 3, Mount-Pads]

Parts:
H901, H902, H903, H904: MOUNT-PAD-ROUND2.8; 2,8-PAD

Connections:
GND: H901.B2,8, H902.B2,8, H903.B2,8, H904.B2,8; also elsewhere on the board

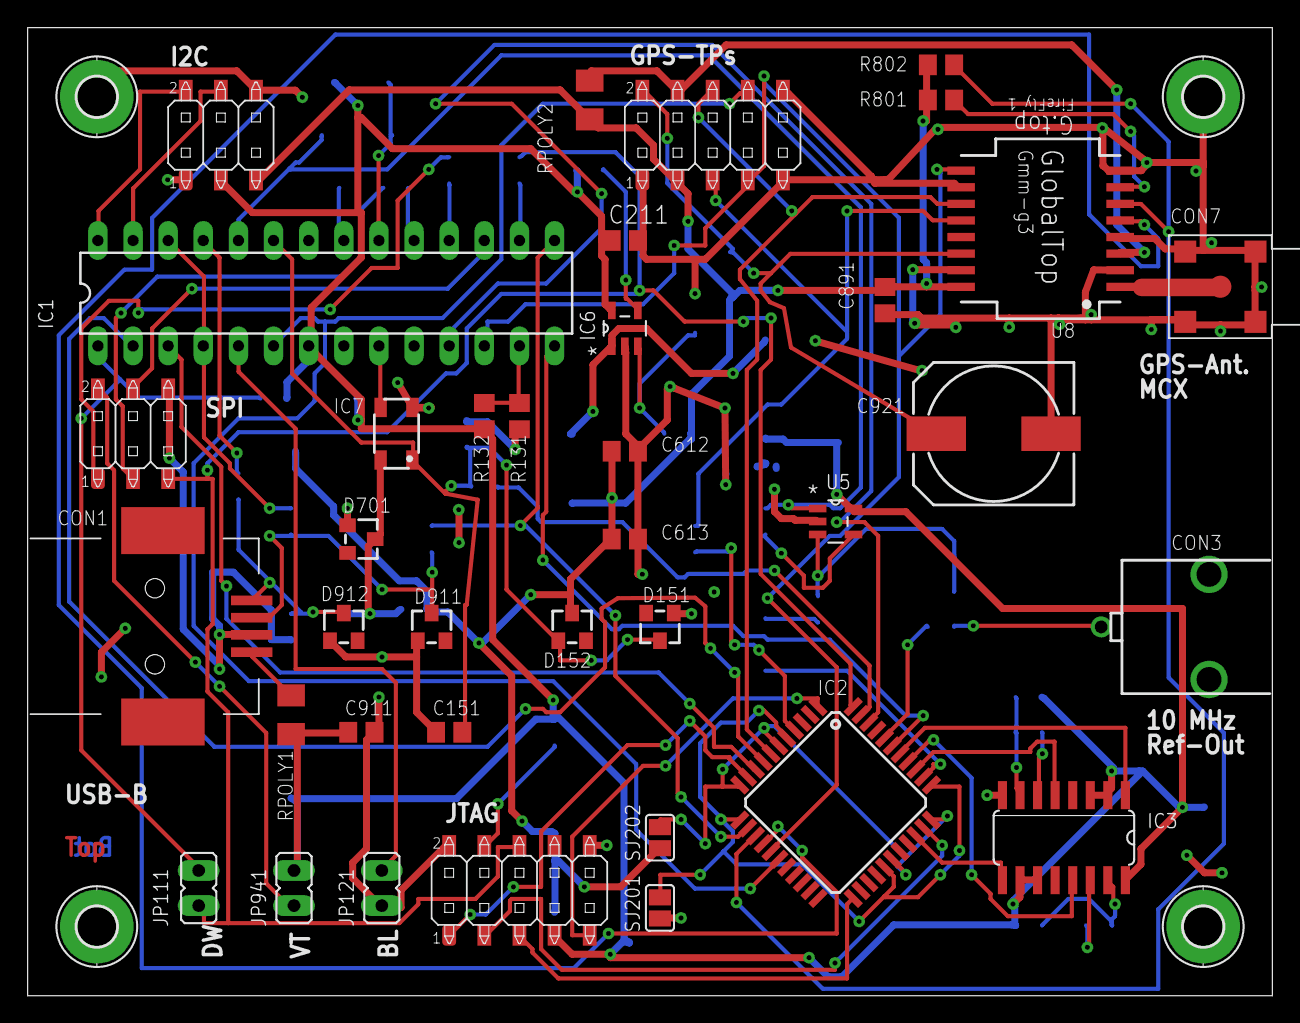
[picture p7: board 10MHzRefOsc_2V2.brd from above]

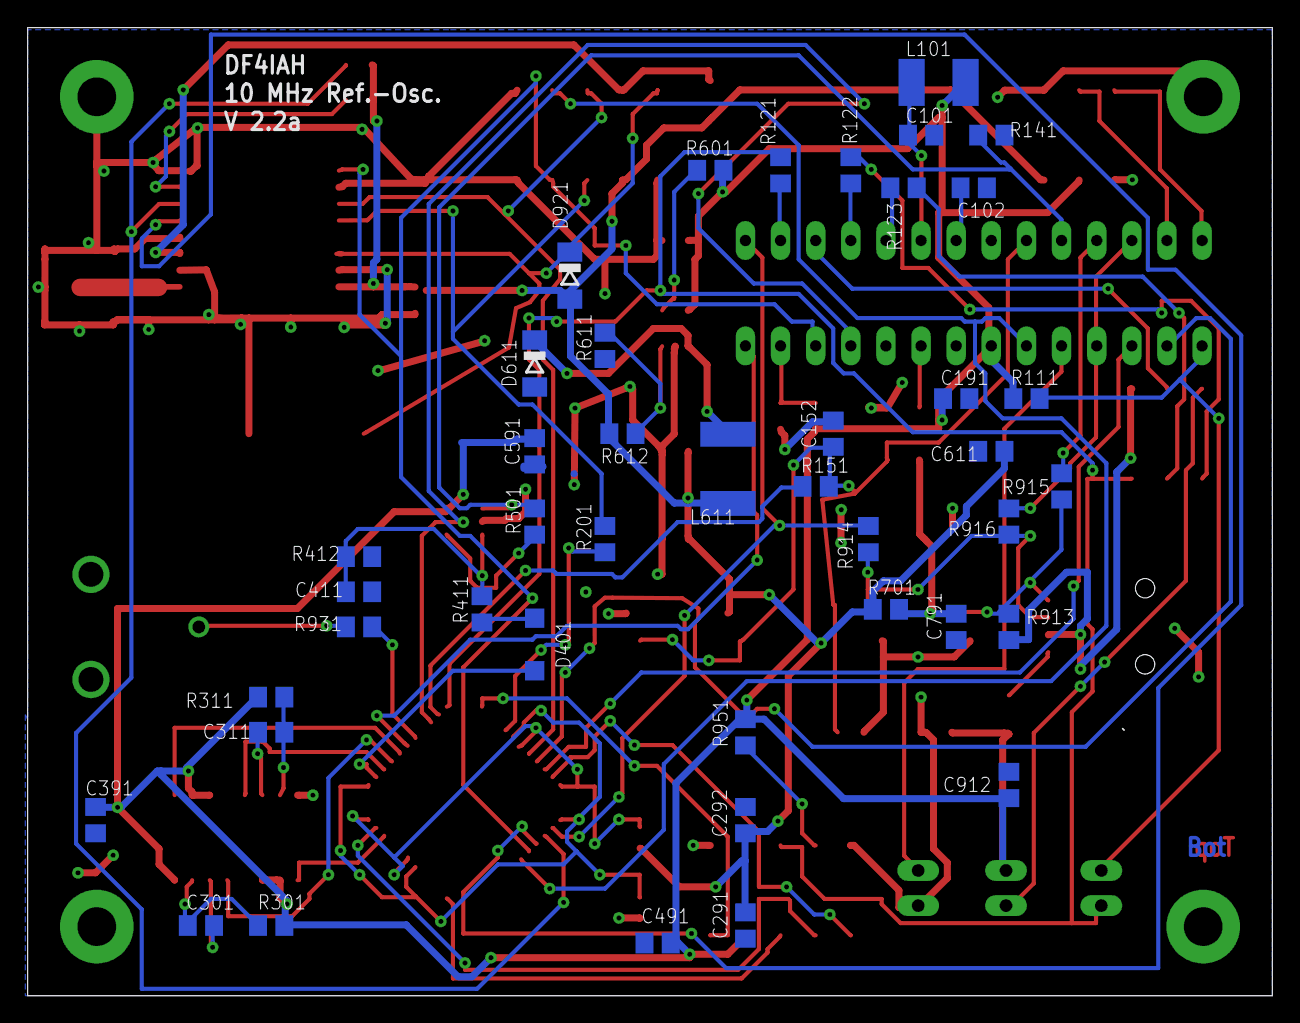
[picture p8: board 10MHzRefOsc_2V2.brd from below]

Board: 2 copper layers, 90.0 x 70.0 mm, 83 parts (42 on the bottom side), 69 nets.

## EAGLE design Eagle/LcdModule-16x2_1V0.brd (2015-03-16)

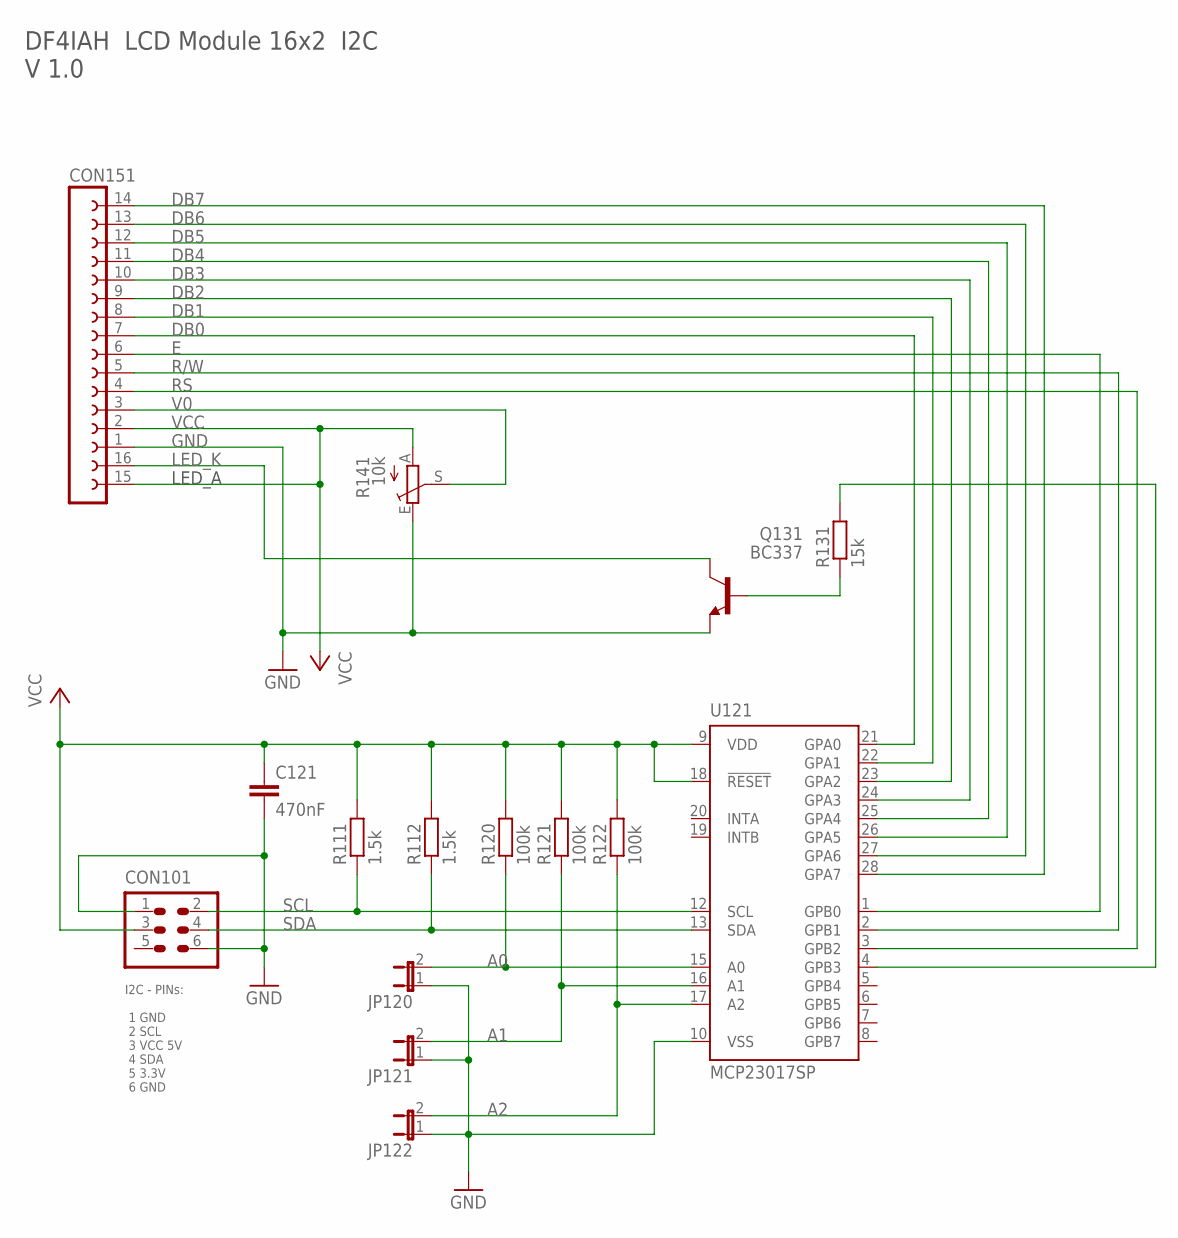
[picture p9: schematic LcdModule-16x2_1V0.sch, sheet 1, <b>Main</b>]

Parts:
C121: 470nF; C0805
CON101: HEADER-2X3SMD; 2X03SMD
CON151: CON_LCDBRD_16W
JP120, JP121, JP122: JP1E; JP1
Q131: BC337; TO92
R111, R112: 1.5k; R0805
R120, R121, R122: 100k; R0805
R131: 15k; R0805
R141: 10k; PT-10
U121: MCP23017SP; DIL28-3

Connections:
A0: JP120.2, R120.1, U121.15 (A0)
A1: JP121.2, R121.1, U121.16 (A1)
A2: JP122.2, R122.1, U121.17 (A2)
DB0: CON151.7, U121.21 (GPA0)
DB1: CON151.8, U121.22 (GPA1)
DB2: CON151.9, U121.23 (GPA2)
DB3: CON151.10, U121.24 (GPA3)
DB4: CON151.11, U121.25 (GPA4)
DB5: CON151.12, U121.26 (GPA5)
DB6: CON151.13, U121.27 (GPA6)
DB7: CON151.14, U121.28 (GPA7)
E: CON151.6, U121.1 (GPB0)
GND: C121.2, CON101.1, CON101.6, CON151.1, JP120.1, JP121.1, JP122.1, Q131.1 (E), R141.E, U121.10 (VSS); also elsewhere on the board
LED: R131.2, U121.4 (GPB3)
LED_K: CON151.16, Q131.3 (C)
unnamed: Q131.2 (B), R131.1
R/W: CON151.5, U121.2 (GPB1)
RS: CON151.4, U121.3 (GPB2)
SCL: CON101.2, R111.1, U121.12 (SCL)
SDA: CON101.4, R112.1, U121.13 (SDA)
V0: CON151.3, R141.S
VCC: C121.1, CON101.3, CON151.2, CON151.15, R111.2, R112.2, R120.2, R121.2, R122.2, R141.A, U121.9 (VDD), U121.18 (!RESET)

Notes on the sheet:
DF4IAH LCD Module 16x2 I2C V 1.0
I2C - PINs: 1 GND 2 SCL 3 VCC 5V 4 SDA 5 3.3V 6 GND
LED_A

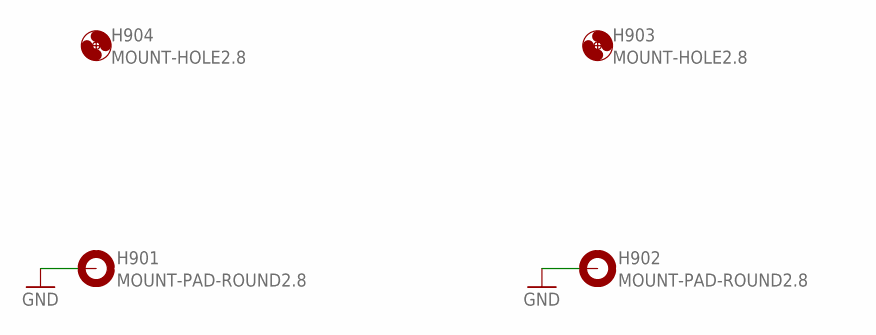
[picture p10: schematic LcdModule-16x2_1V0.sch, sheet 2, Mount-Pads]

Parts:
H901, H902: MOUNT-PAD-ROUND2.8; 2,8-PAD
H903, H904: MOUNT-HOLE2.8; 2,8

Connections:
GND: H901.B2,8, H902.B2,8; also elsewhere on the board

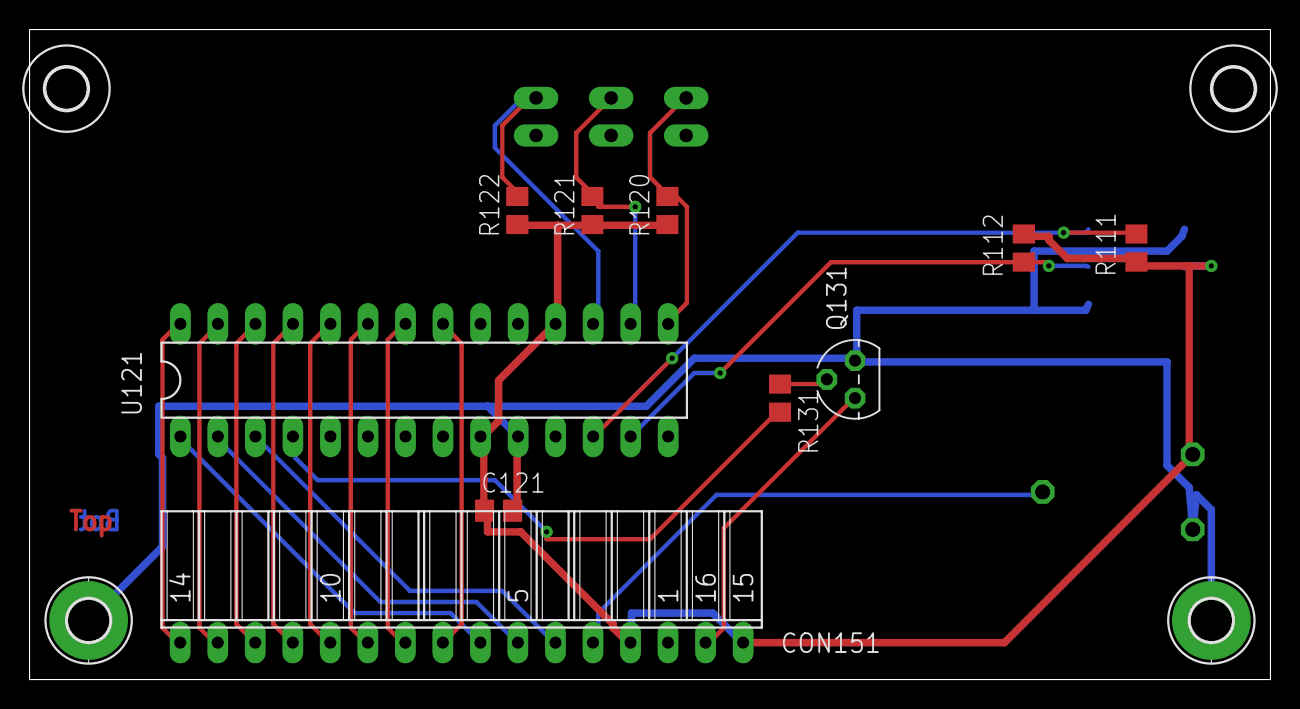
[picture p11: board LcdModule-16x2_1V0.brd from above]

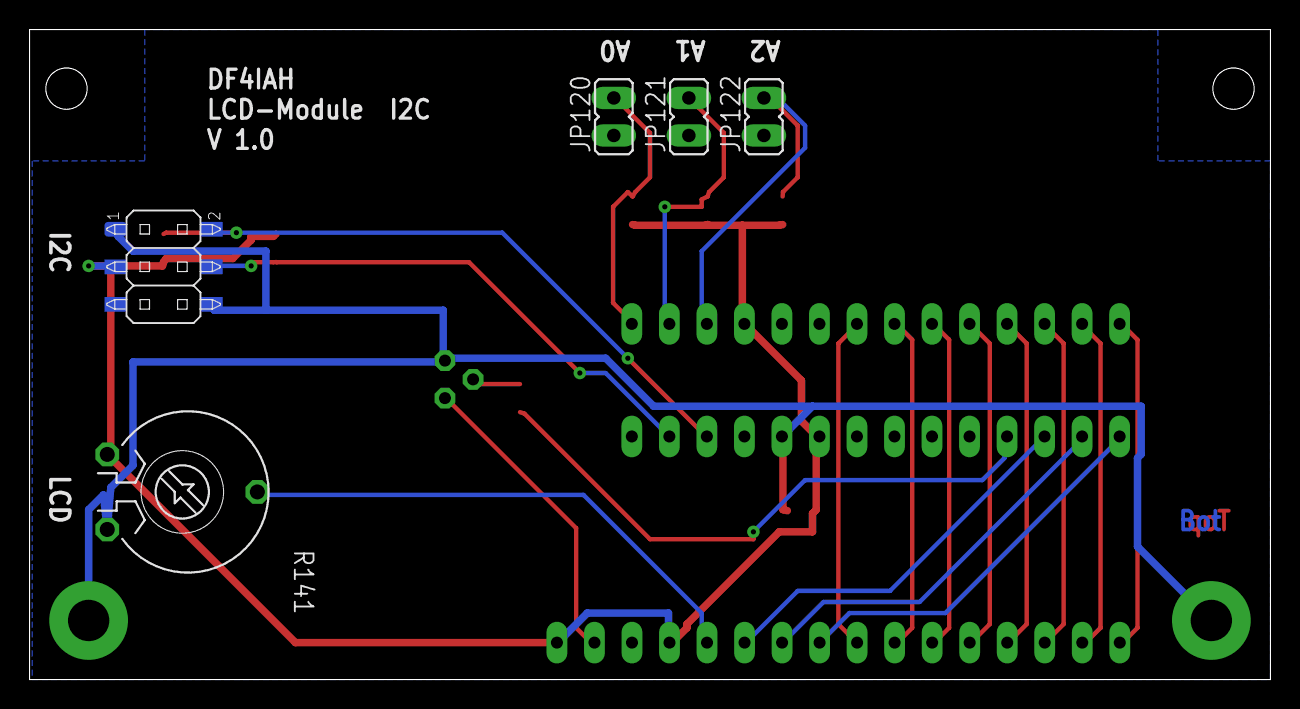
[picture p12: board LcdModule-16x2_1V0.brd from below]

Board: 2 copper layers, 84.0 x 44.0 mm, 19 parts (5 on the bottom side), 22 nets.

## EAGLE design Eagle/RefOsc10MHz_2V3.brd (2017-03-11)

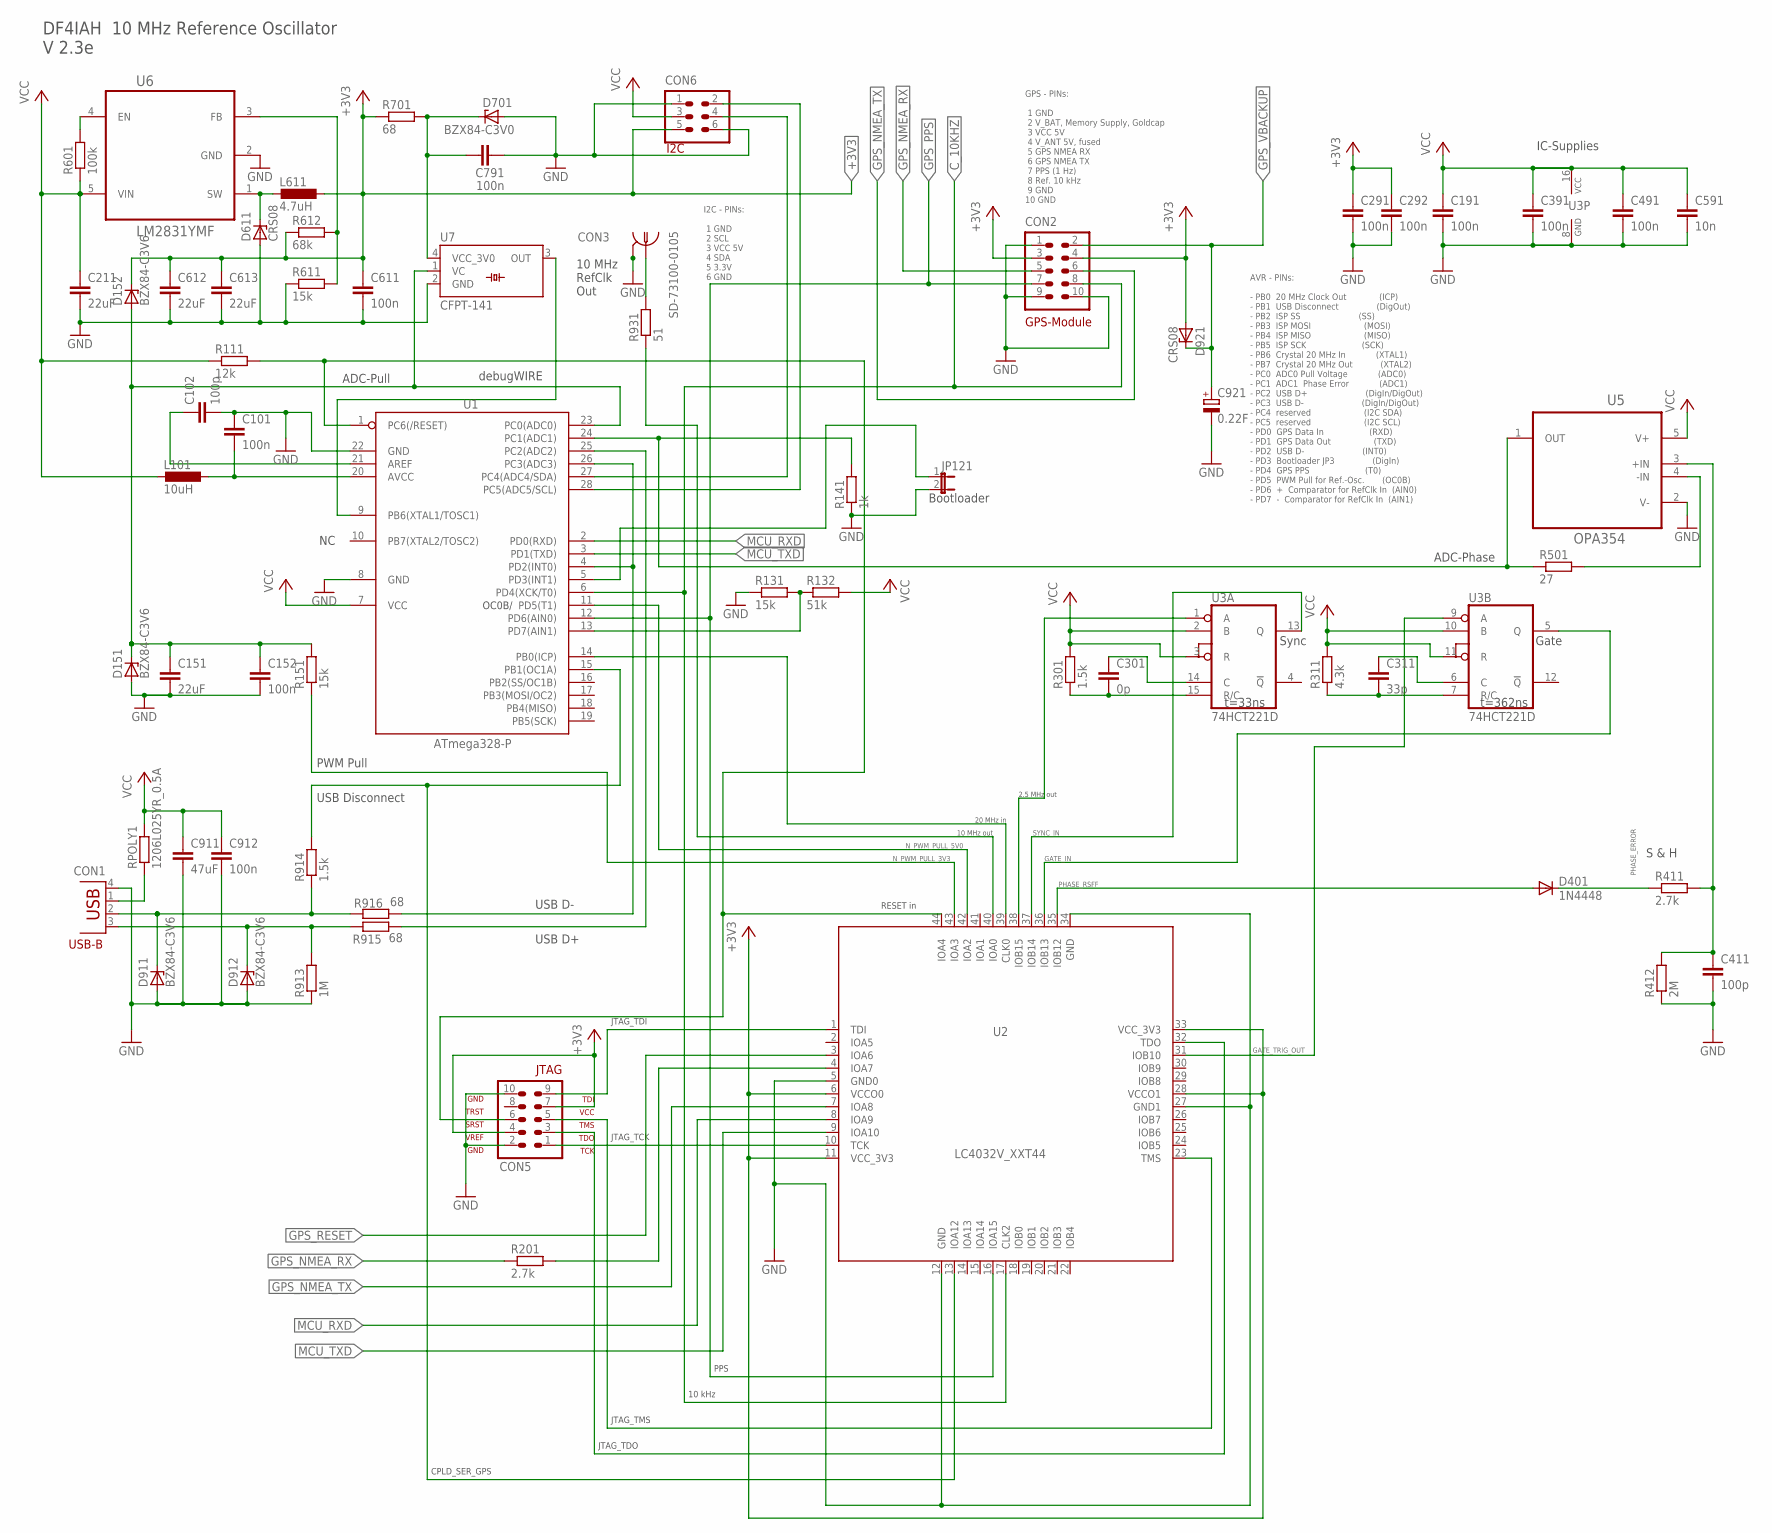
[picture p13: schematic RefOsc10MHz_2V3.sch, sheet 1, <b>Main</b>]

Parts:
C101, C152, C191, C291, C292, C391, C491, C611, C791, C912: 100n; C0805
C102, C411: 100p; C0805
C151, C211, C612, C613: 22uF; C0805
C301: 0p; C0805
C311: 33p; C0805
C591: 10n; C0805
C911: 47uF; C0805
C921: 0.22F; 140CLH-1010
CON1: TYCO-AMP_USBUSB-B_SMT; TYCO-AMP_USB-B_SMT
CON2: HEADER-2X5; 2X05
CON3: SD-73100-0105; MOLEX_BNC-JACK-50R_SD-73100-0105
CON5: AVR-JTAG-10
CON6: HEADER-2X3; 2X03
D151, D152, D911, D912: BZX84-C3V6; TO236
D401: 1N4448; DO35-7
D611, D921: CRS08; SOD80C
D701: BZX84-C3V0; TO236
JP121: JP1E; JP1
L101: 10uH; L1812
L611: 4.7uH; L5650M
R111: 12k; R0805
R131, R151, R611: 15k; R0805
R132: 51k; R0805
R141: 1k; R0805
R201, R411: 2.7k; R0805
R301, R914: 1.5k; R0805
R311: 4.3k; R0805
R412: 2M; R0805
R501: 27; R0805
R601: 100k; R0805
R612: 68k; R0805
R701, R915, R916: 68; R0805
R913: 1M; R0805
R931: 51; R0805
RPOLY1: 1206L025YR_0.5A; M1206
U1: ATmega328-P; DIL28-3
U2: LC4032V_XXT44; TQFP44
U3: 74HCT221D; SO16
U5: OPA354; SOT-23-5
U6: LM2831YMF; SOT95P280X145-5N
U7: CFPT-141

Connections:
+3V0: C791.1, D701.C, R701.2, U7.4 (VCC_3V0)
+3V3: C291.1, C292.1, C611.1, C612.1, C613.1, CON2.3, CON2.4, CON5.4, CON5.7, CON6.5, D152.C, D921.A, L611.1, R612.1, R701.1, U2.6 (VCCO0), U2.11 (VCC_3V3), U2.28 (VCCO1), U2.33 (VCC_3V3); also elsewhere on the board
ADC_PHASE: R141.2, R501.1, U1.24 (PC1(ADC1)), U5.1 (OUT)
ADC_PHASE_SAMPLEHOLD: C411.1, R411.2, R412.2, U5.3 (+IN)
AIN1: R131.2, R132.1, U1.13 (PD7(AIN1))
AREF: C102.1, U1.21 (AREF)
AVCC: C101.2, L101.1, U1.20 (AVCC)
CPLD_GPS_NMEA_RX: R201.2, U2.4 (IOA7)
C_2MHZ5: U2.38 (IOB15), U3.1 (A)
C_10KHZ: CON2.8, U1.6 (PD4(XCK/T0)), U2.17 (CLK2)
C_10MHZ: CON3.1, R931.2
C_20MHZ: U1.14 (PB0(ICP)), U2.39 (CLK0)
D_10MHZ: R931.1, U2.40 (IOA0)
EN: R601.2, U6.4 (EN)
FB: R611.2, R612.2, U6.3 (FB)
GATE_IN: U2.36 (IOB13), U3.5 (Q)
GATE_TRIG_OUT: U2.31 (IOB10), U3.9 (A)
GND: C101.1, C102.2, C151.2, C152.2, C191.2, C211.2, C291.2, C292.2, C391.2, C411.2, C491.2, C591.2, C611.2, C612.2, C613.2, C791.2, C911.2, C912.2, C921.-, CON1.4 (GND), CON2.1, CON2.9, CON2.10, CON3.2, CON3.3, CON5.2, CON5.10, CON6.1, CON6.6, D151.A, D611.A, D701.A, D911.A, D912.A, JP121.2, R131.1, R141.1, R412.1, R611.1, R913.1, U1.8 (GND), U1.22 (GND), U2.5 (GND0), U2.12 (GND), U2.27 (GND1), U2.34 (GND), U3.8 (GND), U5.2 (V-), U6.2 (GND), U7.2 (GND); also elsewhere on the board
GPS_NMEA_RX: CON2.5, R201.1; also elsewhere on the board
GPS_NMEA_TX: CON2.6, U2.7 (IOA8); also elsewhere on the board
GPS_PPS: CON2.7, U1.12 (PD6(AIN0)), U2.16 (IOA15); also elsewhere on the board
GPS_RESET: U2.3 (IOA6); also elsewhere on the board
GPS_VBACKUP: C921.+, CON2.2, D921.C; also elsewhere on the board
INT1: JP121.1, U1.5 (PD3(INT1))
JTAG_TCK: CON5.1, U2.10 (TCK)
JTAG_TDI: CON5.9, U2.1 (TDI)
JTAG_TDO: CON5.3, U2.32 (TDO)
JTAG_TMS: CON5.5, U2.23 (TMS)
MCU_RXD: U1.2 (PD0(RXD)), U2.8 (IOA9)
MCU_TXD: U1.3 (PD1(TXD)), U2.9 (IOA10)
unnamed: CON6.2, U1.28 (PC5(ADC5/SCL))
unnamed: CON6.4, U1.27 (PC4(ADC4/SDA))
unnamed: C311.2, R311.1, U3.7 (R/C)
unnamed: C311.1, U3.6 (C)
unnamed: C301.2, R301.1, U3.15 (R/C)
unnamed: C301.1, U3.14 (C)
N_ADC_PULL: C151.1, C152.1, D151.C, D152.A, R151.2, U1.23 (PC0(ADC0)), U7.1 (VC)
N_PWM_PULL_3V3: R151.1, U2.43 (IOA3)
N_PWM_PULL_5V0: U1.11 (PD5(T1)), U2.42 (IOA2)
N_USB_DISC: R914.2, U1.15 (PB1(OC1A)), U2.13 (IOA12)
N_USB_DMNS: R916.2, U1.4 (PD2(INT0)), U1.26 (PC3(ADC3))
N_USB_DPLS: R915.2, U1.25 (PC2(ADC2))
PHASE_ERROR: D401.C, R411.1
PHASE_RSFF: D401.A, U2.35 (IOB12)
RESET: CON5.6, R111.2, U1.1 (PC6(/RESET)), U2.44 (IOA4)
SW: D611.C, L611.2, U6.1 (SW)
SYNC_IN: U2.37 (IOB14), U3.13 (Q)
TOSC1: U1.9 (PB6(XTAL1/TOSC1)), U7.3 (OUT)
U5_FB: R501.2, U5.4 (-IN)
USB_D_MIN: CON1.2 (D-), D911.C, R914.1, R916.1
USB_D_PLS: CON1.3 (D+), D912.C, R913.2, R915.1
USB_PWR: CON1.1 (VBUS), RPOLY1.1
VCC: C191.1, C211.1, C391.1, C491.1, C591.1, C911.1, C912.1, CON6.3, L101.2, R111.1, R132.2, R301.2, R311.2, R601.1, RPOLY1.2, U1.7 (VCC), U3.2 (B), U3.3 (R), U3.10 (B), U3.11 (R), U3.16 (VCC), U5.5 (V+), U6.5 (VIN)

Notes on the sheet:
debugWIRE
USB-B
AVR - PINs: - PB0 20 MHz Clock Out (ICP) - PB1 USB Disconnect (DigOut) - PB2 ISP SS (SS) - PB3 ISP MOSI (MOSI) - PB4 ISP MISO (MISO) - PB5 ISP SCK (SCK) - PB6 Crystal 20 MHz In (XTAL1) - PB7 Crystal 20 MHz Out (XTAL2) - PC0 ADC0 Pull Voltage (ADC0) - PC1 ADC1 Phase Error (ADC1) - PC2 USB D+ (DigIn/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
10 MHz RefClk Out
Bootloader
Gate
GPS-Module
GPS - PINs: 1 GND 2 V_BAT, Memory Supply, Goldcap 3 VCC 5V 4 V_ANT 5V, fused 5 GPS NMEA RX 6 GPS NMEA TX 7 PPS (1 Hz) 8 Ref. 10 kHz 9 GND 10 GND
S & H
ADC-Phase
PWM Pull
ADC-Pull
Sync
t=33ns
t=362ns
IC-Supplies
20 MHz in
10 MHz out
2.5 MHz out
DF4IAH 10 MHz Reference Oscillator V 2.3e
USB Disconnect
USB D-
USB D+
10 kHz
PPS
RESET in
JTAG_TMS
JTAG_TDO
JTAG_TCK
JTAG_TDI
CPLD_SER_GPS
I2C - PINs: 1 GND 2 SCL 3 VCC 5V 4 SDA 5 3.3V 6 GND
I2C
OC0B/

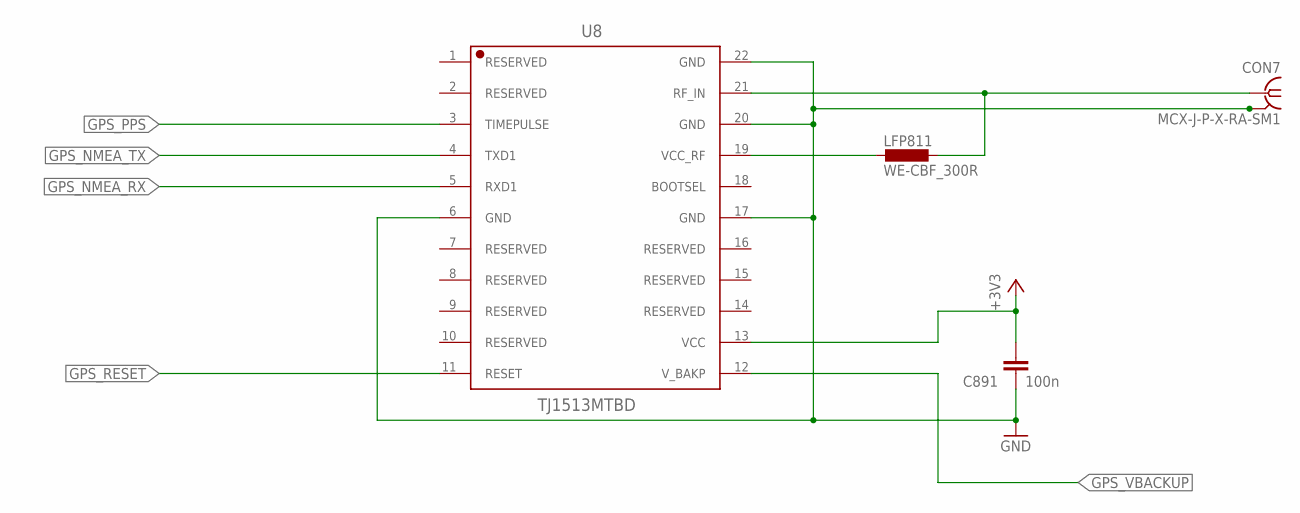
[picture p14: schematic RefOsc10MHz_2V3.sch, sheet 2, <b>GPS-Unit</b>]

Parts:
C891: 100n; C0805
CON7: MCX-J-P-X-RA-SM1
LFP811: WE-CBF_300R; L3216C
U8: TJ1513MTBD

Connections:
+3V3: C891.1, U8.13 (VCC); also elsewhere on the board
GND: C891.2, CON7.2, CON7.3, CON7.4, CON7.5, U8.6 (GND), U8.17 (GND), U8.20 (GND), U8.22 (GND); also elsewhere on the board
GPS_HF: CON7.1, LFP811.1, U8.21 (RF_IN)
GPS_NMEA_RX: U8.5 (RXD1); also elsewhere on the board
GPS_NMEA_TX: U8.4 (TXD1); also elsewhere on the board
GPS_PPS: U8.3 (TIMEPULSE); also elsewhere on the board
GPS_RESET: U8.11 (RESET); also elsewhere on the board
GPS_VBACKUP: U8.12 (V_BAKP); also elsewhere on the board
unnamed: LFP811.2, U8.19 (VCC_RF)


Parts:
H901, H902, H903, H904: MOUNT-PAD-ROUND2.8; 2,8-PAD

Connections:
GND: H901.B2,8, H902.B2,8, H903.B2,8, H904.B2,8; also elsewhere on the board

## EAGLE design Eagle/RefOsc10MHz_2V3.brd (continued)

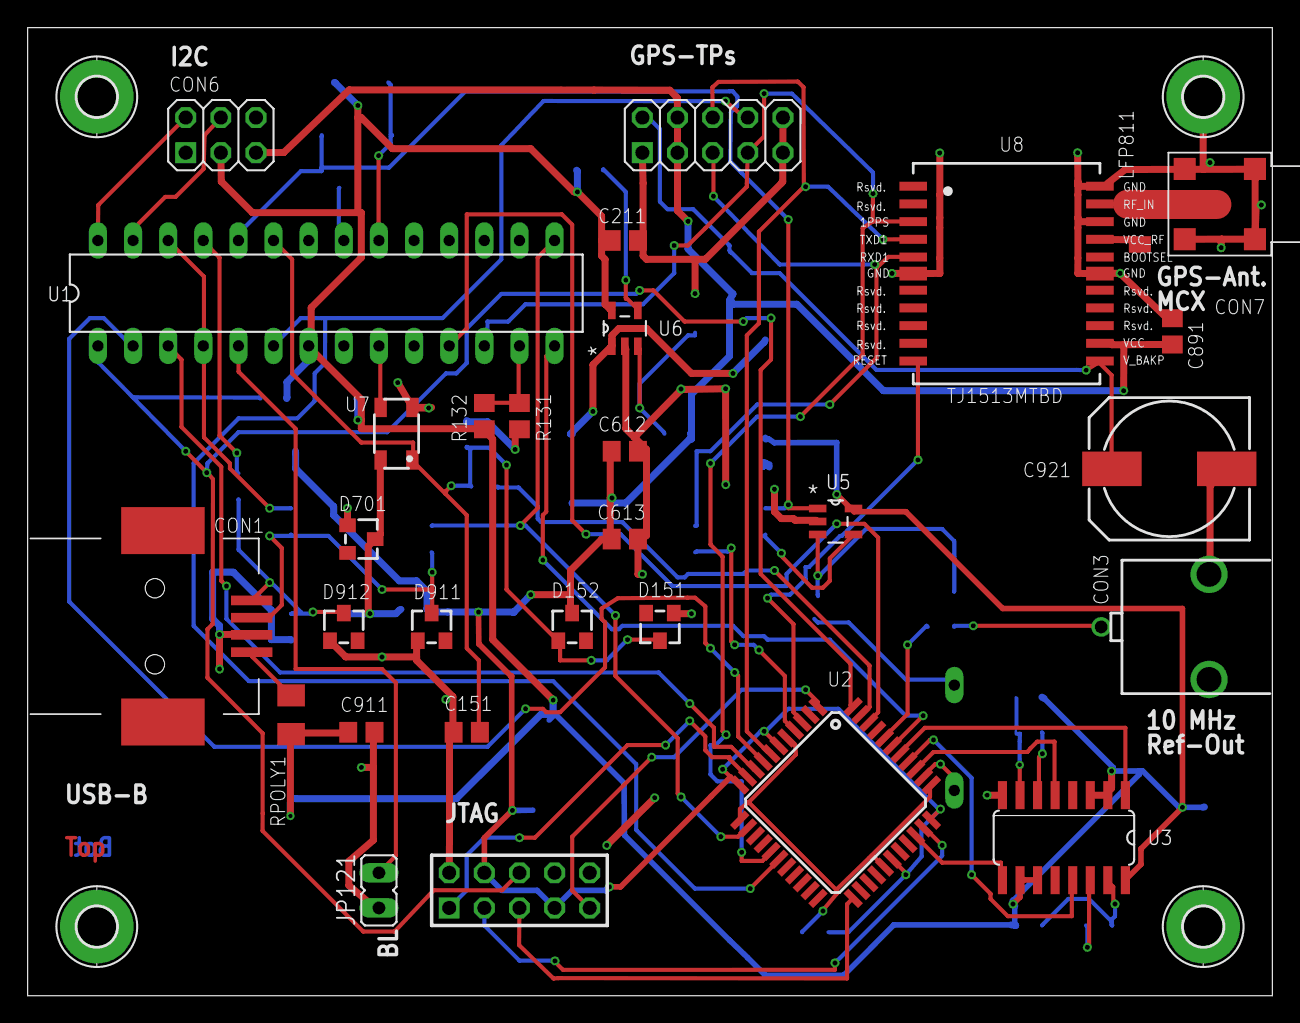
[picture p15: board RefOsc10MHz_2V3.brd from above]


Board: 2 copper layers, 90.0 x 70.0 mm, 72 parts (38 on the bottom side), 55 nets.

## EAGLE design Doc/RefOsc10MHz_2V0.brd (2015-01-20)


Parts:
C1: 47uF; PANASONIC_C
C2, C21, C31, C203, C221: 100n; C0805
C22: 10uF; PANASONIC_B
C32: 100p; C0805
C51, C911, C921, C922, C931, C951: 10n; C0805
C71: 10p; C0805
C72: 33p; C0805
C81: 0.22F; PANASONIC_C
C211, C212, C213: 22uF; A/3216-18W
CON1: TYCO-AMP_USBUSB-B_SMT; TYCO-AMP_USB-B_SMT
CON2: HEADER-2X5SMD; 2X5SMD
CON3: SD-73100-0105; MOLEX_BNC-JACK-50R_SD-73100-0105
CON4: AVR-ISP-6SMD; 2X3SMD
CON5: AVR-JTAG-10SMD; 2X5SMD
CON6: HEADER-2X3SMD; 2X03SMD
D1, D2: BZX84-C3V6; TO236
D82, D211: CRS08; SOT23
D201, D202: BZX84-C2V7; TO236
D221: BZX84-C3V0; TO236
IC1: ATmega328-P; DIL28-3
IC2: LC4032V_XXT44; TQFP44
IC3: 74HCT221D; SO16
IC4: CFPT-141
IC5: LMH6645MF; SOT95P280X145-5N
IC6: LM2831YMF; SOT95P280X145-5N
JP1, JP2, JP3: SJW
L31: 10uH; L1812
L211: 4.7uH; L5650M
R1, R2: 68; R0805
R3, R71: 1.5k; R0805
R4: 1M; R0805
R13: 15k; R0805
R21, R22, R23, R25: 2.7k; R0805
R31: 50k; RTRIMTS63Y
R41: 12k; R0805
R51, R52, R81: 1k; R0805
R61: 51; R0805
R72: 10k; RTRIMTS63Y
R211, R212: 10k; R0805
R213: 100k; R0805
R221: 56; R0805
RPOLY1: 1206L025YR_0.5A; M1206
RPOLY2: 1206L012WR_0.1A; M1206
SJ21, SJ22: SJ

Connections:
+3V0: C221.1, D221.C, IC4.4 (VCC_3V0), R221.2
+3V3: C203.1, C212.+, C213.+, C921.1, C922.1, CON2.3, CON6.5, D82.1 (A), D202.C, L211.1, R211.1, R221.1, RPOLY2.2, SJ22.2; also elsewhere on the board
ADC_PHASE: IC1.24 (PC1(ADC1)), IC5.1 (VOUT), IC5.4 (VIN-), R52.2
ADC_PHASE_PULLHOLD: C51.1, IC5.3 (VIN+), R51.2
AIN1: IC1.13 (PD7(AIN1)), R31.2 (S)
AREF: C32.1, IC1.21 (AREF)
AVCC: C31.2, IC1.20 (AVCC), L31.1
CPLD_GPS_NMEA_TX: IC2.7 (IOA8), R25.2
C_2MHZ5: IC2.38 (IOB15), IC3.1 (A)
C_10KHZ: CON2.8, IC1.6 (PD4(XCK/T0)), IC2.17 (CLK2)
C_10MHZ: IC2.40 (IOA0), R61.1
C_20MHZ: IC1.14 (PB0(ICP)), IC2.39 (CLK0)
EN: IC6.5 (EN), R213.2
FB: IC6.3 (FB), R211.2, R212.2
GATE: IC2.36 (IOB13), IC3.5 (Q)
GATE_TRIG: IC2.31 (IOB10), IC3.9 (A)
GND: C1.-, C2.2, C21.2, C22.-, C31.1, C32.2, C51.2, C81.-, C203.2, C211.-, C212.-, C213.-, C221.2, C911.2, C921.2, C922.2, C931.2, C951.2, CON1.4 (GND), CON2.1, CON2.9, CON2.10, CON3.2, CON3.3, CON4.6, CON5.2, CON5.10, CON6.1, CON6.6, D1.A, D2.A, D201.A, D211.1 (A), D221.A, IC1.8 (GND), IC1.22 (AGND), IC3.8 (GND), IC4.2 (GND), IC5.2 (-VS), IC6.2 (GND), JP3.1, R4.1, R31.1 (A), R52.1, R212.1, SJ21.1; also elsewhere on the board
GND_SJ1: IC2.5 (GND0), IC2.12 (GND), IC2.27 (GND1), IC2.34 (GND), SJ21.2
GPS_ANT_PWR: CON2.4, RPOLY2.1
GPS_NMEA_RX: CON2.5, IC2.4 (IOA7); also elsewhere on the board
GPS_NMEA_TX: CON2.6, R25.1; also elsewhere on the board
GPS_PPS: CON2.7, IC1.12 (PD6(AIN0)), IC2.16 (IOA15); also elsewhere on the board
GPS_VBACKUP: C81.+, CON2.2, D82.3 (C); also elsewhere on the board
INT1: IC1.5 (PD3(INT1)), JP3.2
ISP_MISO: CON4.1, R22.1
ISP_MOSI: CON4.4, IC1.17 (PB3(MOSI/OC2))
ISP_SCK: CON4.3, R23.2
ISP_VTARGET: CON4.2, JP2.1
JTAG_SRST: CON4.5, CON5.6, IC2.44 (IOA4), JP1.2, R21.2
JTAG_TCK: CON5.1, IC2.10 (TCK)
JTAG_TDI: CON5.9, IC2.1 (TDI)
JTAG_TDO: CON5.3, IC2.32 (TDO)
JTAG_TMS: CON5.5, IC2.23 (TMS)
JTAG_VREF: CON5.4, R81.1
MCU_RXD: IC1.2 (PD0(RXD)), IC2.8 (IOA9)
MCU_TXD: IC1.3 (PD1(TXD)), IC2.9 (IOA10)
MISO: IC1.18 (PB4(MISO)), R22.2
unnamed: CON6.2, IC1.28 (PC5(ADC5/SCL))
unnamed: CON6.4, IC1.27 (PC4(ADC4/SDA))
unnamed: CON3.1, R61.2
unnamed: C72.2, IC3.7 (R/C), R72.2 (S)
unnamed: C72.1, IC3.6 (C)
unnamed: C71.2, IC3.15 (R/C), R71.1
unnamed: C71.1, IC3.14 (C)
N_ADC_PULL: C21.1, C22.+, D201.C, D202.A, IC1.23 (PC0(ADC0)), IC4.1 (VC), R13.2
N_PWM_PULL: IC1.11 (PD5(T1)), R13.1
N_USB_DISC: IC1.15 (PB1(OC1A)), IC2.13 (IOA12), R3.2
N_USB_DMNS: IC1.4 (PD2(INT0)), IC1.26 (PC3(ADC3)), R1.2
N_USB_DPLS: IC1.25 (PC2(ADC2)), R2.2
PHASE_ERROR: IC2.35 (IOB12), R51.1
RESET: IC1.1 (PC6(/RESET)), JP1.1, R41.2
SCK: IC1.19 (PB5(SCK)), R23.1
SS: IC1.16 (PB2(SS/OC1B)), R21.1
SW: D211.3 (C), IC6.1 (SW), L211.2
SYNC: IC2.37 (IOB14), IC3.13 (Q)
TOSC1: IC1.9 (PB6(XTAL1/TOSC1)), IC4.3 (OUT)
USB_D_MIN: CON1.2 (D-), D1.C, R1.1, R3.1
USB_D_PLS: CON1.3 (D+), D2.C, R2.1, R4.2
USB_PWR: CON1.1 (VBUS), RPOLY1.1
VCC: C1.+, C2.1, C211.+, C911.1, C931.1, C951.1, CON5.7, CON6.3, IC1.7 (VCC), IC3.2 (B), IC3.3 (R), IC3.10 (B), IC3.11 (R), IC3.16 (VCC), IC5.5 (VS+), IC6.4 (V1), JP2.2, L31.2, R31.3 (E), R41.1, R71.2, R72.1 (A), R81.2, R213.1, RPOLY1.2
VCC_3V3_SJ2: IC2.6 (VCCO0), IC2.11 (VCC_3V3), IC2.28 (VCCO1), IC2.33 (VCC_3V3), SJ22.1

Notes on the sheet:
VTarget
debugWIRE
USB-B
AVR - PINs: - PB0 20 MHz Clock Out (ICP) - PB1 USB Disconnect (DigOut) - PB2 ISP SS (SS) - PB3 ISP MOSI (MOSI) - PB4 ISP MISO (MISO) - PB5 ISP SCK (SCK) - PB6 Crystal 20 MHz In (XTAL1) - PB7 Crystal 20 MHz Out (XTAL2) - PC0 ADC0 Pull Voltage (ADC0) - PC1 ADC1 Phase Error (ADC1) - PC2 USB D+ (DigIn/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
10 MHz RefClk Out
Bootloader
Phase-Error
Gate
GPS-Module
GPS - PINs: 1 GND 2 V_BAT, Memory Supply, Goldcap 3 VCC 5V 4 V_ANT 5V, fused 5 GPS NMEA RX 6 GPS NMEA TX 7 PPS (1 Hz) 8 Ref. 10 kHz 9 GND 10 GND
Pull & Hold
ADC-Phase
PWM Pull
ADC-Pull
Sync
t=33ns
t=362ns
IC-Supplies
20 MHz in
10 MHz out
2.5 MHz out
DF4IAH 10 MHz Reference Oscillator V 2.0
USB Disconnect
USB D-
USB D+
SPI - PINs: 1 MISO 2 V-Target 3 SCK 4 MOSI 5 RST 6 GND
10 kHz
Sync in
Gate in
Phase out
PPS
RESET in
Gate Trig out
JTAG_TMS
JTAG_TDO
JTAG_TCK
JTAG_TDI
CPLD_SER_GPS
I2C - PINs: 1 GND 2 SCL 3 VCC 5V 4 SDA 5 3.3V 6 GND
I2C


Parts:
C111: 100n; C0805
CON11: MCX-J-P-X-RA-SM1
IC11: 712-RXM-GNSS-TM-B
LFP111: WE-CBF_300R; L3216C

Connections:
14: IC11.14, LFP111.1
+3V3: C111.1, IC11.8; also elsewhere on the board
GND: C111.2, CON11.2, CON11.3, CON11.4, CON11.5, IC11.1, IC11.10, IC11.12; also elsewhere on the board
GPS_HF: CON11.1, IC11.11, LFP111.2
GPS_NMEA_RX: IC11.3; also elsewhere on the board
GPS_NMEA_TX: IC11.2; also elsewhere on the board
GPS_PPS: IC11.4; also elsewhere on the board
GPS_VBACKUP: IC11.6; also elsewhere on the board



Board: 2 copper layers, 90.0 x 70.0 mm, 77 parts (26 on the bottom side), 63 nets.

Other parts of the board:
U$1, U$2, U$3, U$4: 2,8

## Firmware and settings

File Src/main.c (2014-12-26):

/*****************************************************************************
*
* AVRPROG compatible boot-loader
* Version  : 0.85 (Dec. 2008)
* Compiler : avr-gcc 4.1.2 / avr-libc 1.4.6
* size     : depends on features and startup ( minmal features < 512 words)
* by       : Martin Thomas, Kaiserslautern, Germany
*            eversmith@heizung-thomas.de
*            Additional code and improvements contributed by:
*           - Uwe Bonnes
*           - Bjoern Riemer
*           - Olaf Rempel
*
* License  : Copyright (c) 2006-2008 M. Thomas, U. Bonnes, O. Rempel
*            Free to use. You have to mention the copyright
*            owners in source-code and documentation of derived
*            work. No warranty! (Yes, you can insert the BSD
*            license here)
*
* Tested with ATmega8, ATmega16, ATmega162, ATmega32, ATmega324P,
*             ATmega644, ATmega644P, ATmega128, AT90CAN128
*
* - Initial versions have been based on the Butterfly bootloader-code
*   by Atmel Corporation (Authors: BBrandal, PKastnes, ARodland, LHM)
*
******************************************************************************
*
*  See the makefile and readme.txt for information on how to adapt 
*  the linker-settings to the selected Boot Size (BOOTSIZE=xxxx) and 
*  the MCU-type. Other configurations futher down in this file.
*
*  With BOOT_SIMPLE, minimal features and discarded int-vectors
*  this bootloader has should fit into a a 512 word (1024, 0x400 bytes) 
*  bootloader-section. 
*
******************************************************************************/
// tabsize: 4


#include <stdint.h>
#include <avr/pgmspace.h>   /* required by usbdrv.h */
#include <avr/io.h>
#include <avr/interrupt.h>
#include <avr/wdt.h>
#include <avr/sleep.h>
#include <util/delay.h>

#include "chipdef.h"
#include "main.h"
#include "df4iah_bl_probe.h"
#include "df4iah_bl_usb.h"
#include "df4iah_bl_memory.h"
#include "df4iah_bl_clkPullPwm.h"
#include "usbdrv_bl/usbdrv.h"


#ifndef BOOT_TOKEN											// should be included from chipdef.h --> mega32.h
# define BOOT_TOKEN											0xb00f
# define BOOT_TOKEN_EE_ADR									0x3fe
#endif


// DATA SECTION

/* main */
void (*jump_to_app)(void) 									= (void*) 0x0000;
volatile uint8_t timer0Snapshot 							= 0x00;
uint8_t jumperBlSet											= false;
volatile uint8_t stopAvr 									= false;
usbTxStatus_t usbTxStatus1, usbTxStatus3;


// STRINGS IN CODE SECTION
// PROGMEM const char VENDOR[VENDOR_len] = { 'D', 'F', '4', 'I', 'A', 'H' };


// CODE SECTION

/*
 * @see http://www.nongnu.org/avr-libc/user-manual/group__avr__interrupts.html
 */

#if defined(BOOTLOADERHASNOVECTORS)
# warning "This Bootloader does not link interrupt vectors - see makefile"
/* make the linker happy - it wants to see __vector_default */
void __vector_default(void) { ; }
#endif

/*  VECTOR - TABLE
 *
	Address	Labels	Code 					Comments
	0x7000			jmp RESET 				; Reset Handler
	0x7002			jmp EXT_INT0 			; IRQ0 Handler
	0x7004			jmp EXT_INT1 			; IRQ1 Handler
	0x7006			jmp PCINT0 				; PCINT0 Handler
	0x7008			jmp PCINT1 				; PCINT1 Handler
	0x700A			jmp PCINT2 				; PCINT2 Handler
	0x700C			jmp WDT 				; Watchdog Timer Handler
	0x700E			jmp TIM2_COMPA 			; Timer2 Compare A Handler
	0x7010			jmp TIM2_COMPB 			; Timer2 Compare B Handler
	0x7012			jmp TIM2_OVF 			; Timer2 Overflow Handler
	0x7014			jmp TIM1_CAPT 			; Timer1 Capture Handler
	0x7016			jmp TIM1_COMPA 			; Timer1 Compare A Handler
	0x7018			jmp TIM1_COMPB 			; Timer1 Compare B Handler
	0x701A			jmp TIM1_OVF 			; Timer1 Overflow Handler
	0x701C			jmp TIM0_COMPA 			; Timer0 Compare A Handler
	0x701E			jmp TIM0_COMPB 			; Timer0 Compare B Handler
	0x7020			jmp TIM0_OVF 			; Timer0 Overflow Handler
	0x7022			jmp SPI_STC 			; SPI Transfer Complete Handler
	0x7024			jmp USART_RXC 			; USART, RX Complete Handler
	0x7026			jmp USART_UDRE 			; USART, UDR Empty Handler
	0x7028			jmp USART_TXC 			; USART, TX Complete Handler
	0x702A			jmp ADC 				; ADC Conversion Complete Handler
	0x702C			jmp EE_RDY 				; EEPROM Ready Handler
	0x702E			jmp ANA_COMP 			; Analog Comparator Handler
	0x7030			jmp TWI 				; 2-wire Serial Interface Handler
	0x7032			jmp SPM_RDY 			; Store Program Memory Ready Handler
	;
	0x7033	RESET:	ldi r16, high(RAMEND)	; Main program start
	0x7034			out SPH,r16 			; Set Stack Pointer to top of RAM
 *
 */

//EMPTY_INTERRUPT(INT0_vect);
//EMPTY_INTERRUPT(INT1_vect);
//ISR(INT1_vect, ISR_ALIASOF(INT0_vect));
//EMPTY_INTERRUPT(PCINT0_vect);
//EMPTY_INTERRUPT(PCINT1_vect);
//EMPTY_INTERRUPT(PCINT2_vect);
//EMPTY_INTERRUPT(WDT_vect);
//EMPTY_INTERRUPT(TIMER2_COMPA_vect);
//EMPTY_INTERRUPT(TIMER2_COMPB_vect);
//EMPTY_INTERRUPT(TIMER2_OVF_vect);
//EMPTY_INTERRUPT(TIMER1_CAPT_vect);
//EMPTY_INTERRUPT(TIMER1_COMPA_vect);
//EMPTY_INTERRUPT(TIMER1_COMPB_vect);
//EMPTY_INTERRUPT(TIMER1_OVF_vect);
//EMPTY_INTERRUPT(TIMER0_COMPA_vect);
//EMPTY_INTERRUPT(TIMER0_COMPB_vect);
//EMPTY_INTERRUPT(TIMER0_OVF_vect);
//EMPTY_INTERRUPT(SPI_STC_vect);
//EMPTY_INTERRUPT(USART_RX_vect);
//EMPTY_INTERRUPT(USART_UDRE_vect);
//EMPTY_INTERRUPT(USART_TX_vect);
//EMPTY_INTERRUPT(ADC_vect);
//EMPTY_INTERRUPT(EE_READY_vect);
//EMPTY_INTERRUPT(ANALOG_COMP_vect);
//EMPTY_INTERRUPT(TWI_vect);
//EMPTY_INTERRUPT(SPM_READY_vect);

//ISR(INT1_vect) {
//	send_error_msg();
//}


static inline void vectortable_to_bootloader(void) {
	cli();
	asm volatile									// set active vector table into the Bootloader section
	(
		"ldi r24, %1\n\t"
		"out %0, r24\n\t"
		"ldi r24, %2\n\t"
		"out %0, r24\n\t"
		:
		: "i" (_SFR_IO_ADDR(MCUCR)),
		  "i" (1<<IVCE),
		  "i" (1<<IVSEL)
		: "r24"
	);
}

static inline void wdt_init() {
	cli();
	wdt_reset();
	wdt_disable();
}

static inline void app_startup_check()
{
	// look for a BOOT marker in the EEPROM and do not jump to the Firmware when it is found at its place
	uint16_t tokenVal = 0;
	memory_bl_readEEpromPage((uint8_t*) &tokenVal, sizeof(tokenVal), BOOT_TOKEN_EE_ADR);
	if (tokenVal != BOOT_TOKEN) {
		// check for jumper-setting and for a valid jump-table entry
		uint16_t code =  0;
		memory_bl_readFlashPage((uint8_t*) &code, sizeof(code), 0x0000);
		if ((!jumperBlSet) && (code == 0x940c)) {		// JMP instruction
			probe_bl_close();
			cli();
			jump_to_app();								// jump to firmware section
		}

	} else {
		/* INHIBIT jump_to_app() - remove one time token */
		uint16_t clearVal = 0xffff;
		memory_bl_writeEEpromPage((uint8_t*) &clearVal, sizeof(clearVal), BOOT_TOKEN_EE_ADR);
	}
}

void give_away(void)
{
	wdt_reset();
	usbPoll();
	clkPullPwm_bl_togglePin();
}


int main(void)
{
	cli();
	vectortable_to_bootloader();

	PRR    = 0xEF;										// disable all modules within the Power Reduction Register
	ACSR  |= _BV(ACD);									// switch on Analog Comparator Disable
	DIDR1 |= (0b11 << AIN0D);							// disable digital input buffers on AIN0 and AIN1

	for (;;) {
		wdt_init();
		probe_bl_init();
		app_startup_check();							// try to start the application FIRMWARE

		clkPullPwm_bl_init();
		usb_bl_init();									// starts at 67 ms after power-up, ends at 316 ms after power-up

		stopAvr = false;
		sei();											// ENABLE interrupt
		while(!stopAvr) {								// falls out when DISCONNECT message is received
			give_away();
		}
		cli();											// DISABLE interrupt

		usb_bl_close();
		clkPullPwm_bl_close();
		//	probe_bl_close();
		//	wdt_close();
	}

	return 0;
}

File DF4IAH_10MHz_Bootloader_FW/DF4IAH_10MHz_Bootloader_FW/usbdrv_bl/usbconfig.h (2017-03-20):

/* Name: usbconfig.h
 * Project: V-USB, virtual USB port for Atmel's(r) AVR(r) microcontrollers
 * Author: Christian Starkjohann
 * Creation Date: 2005-04-01
 * Tabsize: 4
 * Copyright: (c) 2005 by OBJECTIVE DEVELOPMENT Software GmbH
 * License: GNU GPL v2 (see License.txt), GNU GPL v3 or proprietary (CommercialLicense.txt)
 */

#ifndef __usbconfig_h_included__
#define __usbconfig_h_included__

/*
General Description:
This file is an example configuration (with inline documentation) for the USB
driver. It configures V-USB for USB D+ connected to Port D bit 2 (which is
also hardware interrupt 0 on many devices) and USB D- to Port D bit 4. You may
wire the lines to any other port, as long as D+ is also wired to INT0 (or any
other hardware interrupt, as long as it is the highest level interrupt, see
section at the end of this file).
+ To create your own usbconfig.h file, copy this file to your project's
+ firmware source directory) and rename it to "usbconfig.h".
+ Then edit it accordingly.
*/

/* ---------------------------- Hardware Config ---------------------------- */

#define USB_CFG_IOPORTNAME      C
/* This is the port where the USB bus is connected. When you configure it to
 * "B", the registers PORTB, PINB and DDRB will be used.
 */
#define USB_CFG_DMINUS_BIT      3
/* This is the bit number in USB_CFG_IOPORT where the USB D- line is connected.
 * This may be any bit in the port.
 */
#define USB_CFG_DPLUS_BIT       2
/* This is the bit number in USB_CFG_IOPORT where the USB D+ line is connected.
 * This may be any bit in the port. Please note that D+ must also be connected
 * to interrupt pin INT0! [You can also use other interrupts, see section
 * "Optional MCU Description" below, or you can connect D- to the interrupt, as
 * it is required if you use the USB_COUNT_SOF feature. If you use D- for the
 * interrupt, the USB interrupt will also be triggered at Start-Of-Frame
 * markers every millisecond.]
 */
#ifndef USB_CFG_CLOCK_KHZ
# define USB_CFG_CLOCK_KHZ       (F_CPU/1000)
#endif
/* Clock rate of the AVR in kHz. Legal values are 12000, 12800, 15000, 16000,
 * 16500, 18000 and 20000. The 12.8 MHz and 16.5 MHz versions of the code
 * require no crystal, they tolerate +/- 1% deviation from the nominal
 * frequency. All other rates require a precision of 2000 ppm and thus a
 * crystal!
 * Since F_CPU should be defined to your actual clock rate anyway, you should
 * not need to modify this setting.
 */
#define USB_CFG_CHECK_CRC       0
/* Define this to 1 if you want that the driver checks integrity of incoming
 * data packets (CRC checks). CRC checks cost quite a bit of code size and are
 * currently only available for 18 MHz crystal clock. You must choose
 * USB_CFG_CLOCK_KHZ = 18000 if you enable this option.
 */

/* ----------------------- Optional Hardware Config ------------------------ */

#define USB_CFG_PULLUP_IOPORTNAME   B
/* If you connect the 1.5k pullup resistor from D- to a port pin instead of
 * V+, you can connect and disconnect the device from firmware by calling
 * the macros usbDeviceConnect() and usbDeviceDisconnect() (see usbdrv.h).
 * This constant defines the port on which the pullup resistor is connected.
 */
#define USB_CFG_PULLUP_BIT          1
/* This constant defines the bit number in USB_CFG_PULLUP_IOPORT (defined
 * above) where the 1.5k pullup resistor is connected. See description
 * above for details.
 */

/* --------------------------- Functional Range ---------------------------- */
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

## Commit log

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2014-11-27 avr_DF4IAH_Bootloader - BrownOutDetection=2.7V, DebugWire=on, ISP=on
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2014-11-29 avr_DF4IAH_Bootloader - init_serial() fixed
    [main.c, usbconfig.h]
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2014-12-06 avr_DF4IAH_Bootloader - max. current corrected
    [main.c, usbconfig.h]
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2014-12-24 avr_DF4IAH_Bootloader - try new swap bootloader and memory layout
    [main.c]
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2014-12-26 avr_DF4IAH_Bootloader - switch off modules that are not needed, USB power: 210 mA
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2014-12-29 avr_DF4IAH_Bootloader - toggle PIN not masked correctly
2014-12-29 avr_DF4IAH_Bootloader - toggle PIN not masked correctly (2)
2014-12-29 avr_DF4IAH_Bootloader - toggle PIN not masked correctly (3)
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2014-12-31 avr_DF4IAH_Bootloader - startup PWM value up-heated oscillator
2015-01-01 avr_DF4IAH_Bootloader - startup PWM value up-heated oscillator (2)
    [df4iah_bl_main.h]
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2015-01-15 avr_DF4IAH_Bootloader - Doc - Eagle: last updates of the circuit added (V2.0)
    [RefOsc10MHz_2V0.brd, RefOsc10MHz_2V0.sch]
2015-01-15 avr_DF4IAH_Bootloader - CPLD - ignore *.log files - try to remove Sync signal and switch from 2.5 MHz to 10.0 MHz. CPLD allows this with tD = 6.00 ns.
2015-01-17 avr_DF4IAH_Bootloader - Doc - Eagle: I2C header added
    [RefOsc10MHz_2V0.brd, RefOsc10MHz_2V0.sch]
2015-01-18 avr_DF4IAH_Bootloader - Doc - Eagle: USB-B and BNC connectors changed
    [RefOsc10MHz_2V0.brd, RefOsc10MHz_2V0.sch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]
2015-01-18 avr_DF4IAH_Bootloader - Doc - Eagle: ISP-Connector changed from old 10 to new 6 pin variant
    [RefOsc10MHz_2V0.brd, RefOsc10MHz_2V0.sch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]
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2015-01-20 avr_DF4IAH_Bootloader - Doc - Eagle: V2.0.1 manufactured by PCB-Pool - corrections needed
    [RefOsc10MHz_2V0.brd]
2015-01-20 avr_DF4IAH_Bootloader - Doc - Eagle: V2.0.1 manufactured by PCB-Pool - corrections needed (2)
2015-01-26 avr_DF4IAH_Bootloader - Doc - Eagle: setting-up V3.0
    [RefOsc10MHz_3V0.brd, RefOsc10MHz_3V0.sch]
2015-01-26 avr_DF4IAH_Bootloader - Doc - Eagle: V3.0 - REAR panel connected
    [RefOsc10MHz_3V0.brd, RefOsc10MHz_3V0.sch]
2015-01-27 avr_DF4IAH_Bootloader - Doc - Eagle: V2.1 after manufacturing by PCB-Pool - findings to be fixed
    [RefOsc10MHz_2V1.brd, RefOsc10MHz_2V1.sch]
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2015-01-27 avr_DF4IAH_Bootloader - Doc - Eagle: V2.1 after manufacturing by PCB-Pool - findings to be fixed (2) - BNC-Drills size doubled, Goldcap bigger than assumed, switching converter had wrong PIN assignme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
    [RefOsc10MHz_2V1.brd, RefOsc10MHz_2V1.sch]
2015-01-27 avr_DF4IAH_Bootloader - Doc - Eagle: V2.1 after manufacturing by PCB-Pool - findings to be fixed (3) - take big C211 from bottom to top.
    [RefOsc10MHz_2V1.brd, RefOsc10MHz_2V1.sch]
2015-01-28 avr_DF4IAH_Bootloader - Doc - Eagle: V3.0 - FPGA and MMU, first attempt, added
    [RefOsc10MHz_3V0.brd, RefOsc10MHz_3V0.sch]
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2015-02-01 avr_DF4IAH_Bootloader - Doc - Eagle: V2.1 after manufacturing by PCB-Pool - findings to be fixed (4) - change R81 from 1k to 150Ohm, 3.3V regulator corrected.
    [RefOsc10MHz_2V1.brd, RefOsc10MHz_2V1.sch]
2015-02-02 avr_DF4IAH_Bootloader - Doc - Eagle: V1.3 added
    [RefOsc10MHz_1V3.brd, RefOsc10MHz_1V3.sch]
2015-02-04 avr_DF4IAH_Bootloader - Doc - Eagle: V3.0 - MMU (AVR ATmega) moved into FPGA using a free MMU core from opencores.org.
    [RefOsc10MHz_3V0.brd, RefOsc10MHz_3V0.sch]
2015-02-04 avr_DF4IAH_Bootloader - Doc - Eagle: V3.0 - xilinx_devices_V6.lbr containing XC7-Artix added (2)
    [RefOsc10MHz_3V0.brd, RefOsc10MHz_3V0.sch]
2015-02-05 avr_DF4IAH_Bootloader - Doc - Eagle: structuring into V1.x, V2.x and V3.x (2)
    [RefOsc10MHz_1V3.brd, RefOsc10MHz_1V3.sch, RefOsc10MHz_2V1.brd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]
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2015-02-07 avr_DF4IAH_Bootloader - Doc - Eagle: V2.1 - OP-Amps U4 and U5 added/changed
    [RefOsc10MHz_2V1.brd, RefOsc10MHz_2V1.sch]
2015-02-15 avr_DF4IAH_Bootloader - Doc - Eagle: V2.1 - Sample&Hold - reduce from 10nF to 100pF, components are renamed
    [RefOsc10MHz_2V1.brd, RefOsc10MHz_2V1.sch]
2015-02-15 avr_DF4IAH_Bootloader - Doc - Eagle: V2.1 - Sample&Hold - reduce from 10nF to 100pF, components are renamed (2)
    [RefOsc10MHz_2V1.brd, RefOsc10MHz_2V1.sch]
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2015-02-16 avr_DF4IAH_Bootloader - Doc - Eagle: V2.1 - PWM-Pull - drive not direct from AVR with unstabilized 5.0V but by the CPLD with its stabilized 3.3V instead.
    [RefOsc10MHz_2V1.brd, RefOsc10MHz_2V1.sch]
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2015-02-19 avr_DF4IAH_Bootloader - Doc - Eagle: V2.1 - R411 modified, CPLD pinout changed
    [RefOsc10MHz_2V1.brd, RefOsc10MHz_2V1.sch]
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2015-02-25 avr_DF4IAH_Bootloader - Revert most changes on mega32.h. Moved extras to df4iah_bl_main.h
    [df4iah_bl_main.h]
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2015-03-01 avr_DF4IAH_Bootloader - Doc - Eagle: V2.1 - PWM pull signal via CPLD for clamping signals to defined values. AVR controller @ USB is not voltage regulated, the PWM output is therefore variable in its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
    [RefOsc10MHz_2V1.brd, RefOsc10MHz_2V1.sch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]
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2015-03-16 avr_DF4IAH_Bootloader - Doc - Eagle: V2.1 - LcdModule-16x2_1V0 added, updates for RefOsc10MHz_2V1 also
    [LcdModule-16x2_1V0.brd, LcdModule-16x2_1V0.sch, RefOsc10MHz_2V1.brd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]
2015-03-17 avr_DF4IAH_Bootloader - Doc - Eagle: V2.1 - with GPS module Linx - sent to DirtyPCBs
    [RefOsc10MHz_2V1.GBL, RefOsc10MHz_2V1.GBO, RefOsc10MHz_2V1.GBP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]
2015-03-17 avr_DF4IAH_Bootloader - Doc - Eagle: V2.2 - with GPS module GlobalTop - sent to DirtyPCBs
    [RefOsc10MHz_2V2.GBL, RefOsc10MHz_2V2.GBO, RefOsc10MHz_2V2.GBP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]
2015-03-26 avr_DF4IAH_Bootloader - Doc - Eagle: V2.1 - correction: CRS80 --> CRS08
    [RefOsc10MHz_2V1.brd, RefOsc10MHz_2V1.sch]
2015-03-26 avr_DF4IAH_Bootloader - Doc - Eagle: V2.2 - correction: CRS80 --> CRS08
    [RefOsc10MHz_2V2.brd, RefOsc10MHz_2V2.sch]
2015-03-26 avr_DF4IAH_Bootloader - Doc - Eagle: V2.2 - correction: MCX socket ground not completed
    [RefOsc10MHz_2V2.brd, RefOsc10MHz_2V2.sch]
2015-03-26 avr_DF4IAH_Bootloader - Doc - Eagle: V2.1 - correction: CRS80 --> CRS08 (2)
    [RefOsc10MHz_2V1.brd, RefOsc10MHz_2V1.sch]
2015-03-26 avr_DF4IAH_Bootloader - Doc - Eagle: V3.0 - update of current dev. state
    [RefOsc10MHz_3V0.brd, RefOsc10MHz_3V0.sch]
2015-03-30 avr_DF4IAH_Bootloader - Doc - Eagle: V2.1/V2.2 - removed elkos and replaced it by C0805 MLCCs
    [RefOsc10MHz_2V1.brd, RefOsc10MHz_2V1.sch, RefOsc10MHz_2V2.brd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]
2015-04-09 avr_DF4IAH_Bootloader - Doc - Eagle: V2.3 - added. Contains GPS-module TJ1513MTBD which is based on the MediaTek MT3333 chip-set
    [RefOsc10MHz_2V3.brd, RefOsc10MHz_2V3.sch]
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2015-04-12 avr_DF4IAH_Bootloader - Doc - Eagle: V2.3 - added. Contains GPS-module TJ1513MTBD which is based on the MediaTek MT3333 chip-set (2)
    [RefOsc10MHz_2V3.sch]
2015-04-20 avr_DF4IAH_Bootloader - Doc - Eagle: 2.1, 2.2, 2.3 - three resistors changed
    [RefOsc10MHz_2V1.brd, RefOsc10MHz_2V1.sch, RefOsc10MHz_2V2.brd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]
2015-04-20 avr_DF4IAH_Bootloader - Doc - Eagle: 2.1, 2.2, 2.3 - misplaced R311 fixed (making short at BL jumper)
    [RefOsc10MHz_2V1.brd, RefOsc10MHz_2V2.brd, RefOsc10MHz_2V3.brd]
2015-04-24 avr_DF4IAH_Bootloader - Doc - naming of 10MHz-Ref-Osc corrected (1)
    [10MHzRefOsc_2V1.GBL, 10MHzRefOsc_2V1.GBO, 10MHzRefOsc_2V1.GBP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]
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2015-05-08 avr_DF4IAH_Bootloader - Doc - Eagle: 2.1 - 3.3V adjusting resistors corrected, 2-way jumpers now THT instead of SMT
    [10MHzRefOsc_2V1.brd, 10MHzRefOsc_2V1.sch]
2015-05-08 avr_DF4IAH_Bootloader - Doc - Eagle: 2.2 - 3.3V adjusting resistors corrected
    [10MHzRefOsc_2V2.brd, 10MHzRefOsc_2V2.sch]
2015-05-08 avr_DF4IAH_Bootloader - Doc - Eagle: 2.3 - 3.3V adjusting resistors corrected, 2-way jumpers now THT instead of SMT, GPS-chip package enhanced
    [10MHzRefOsc_2V3.brd, 10MHzRefOsc_2V3.sch]
2016-09-07 avr_DF4IAH_Bootloader - README.md - I2C fixed
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2017-01-30 Doc - V2.3 - V2.3d added and df4iah_*.lbr update
    [RefOsc10MHz_2V3.brd, RefOsc10MHz_2V3.sch]
2017-01-30 Doc - V2.3 - dimension rulers added: 90mm x 70mm
    [RefOsc10MHz_2V3.brd]
2017-03-11 Doc - V2.3e - via 0.6mm --> 0.35mm
    [RefOsc10MHz_2V3.brd, RefOsc10MHz_2V3.sch]
2017-03-19 SW_V2.x.1 - upgrade from Eclipse to AtmelStudio
    [10MHzRefOsc_2V1.GBL, 10MHzRefOsc_2V1.GBO, 10MHzRefOsc_2V1.GBP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]
2017-03-20 HW_V2.1.1 - new branch
    [10MHzRefOsc_2V1.GBL, 10MHzRefOsc_2V1.GBO, 10MHzRefOsc_2V1.GBP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]
2017-03-20 HW_V2.2.1 - new branch
    [10MHzRefOsc_2V1.GBL, 10MHzRefOsc_2V1.GBO, 10MHzRefOsc_2V1.GBP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]
2017-03-20 HW_V2.3.1 - new branch
    [10MHzRefOsc_2V1.GBL, 10MHzRefOsc_2V1.GBO, 10MHzRefOsc_2V1.GBP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]
2017-03-20 LCD_V2.x.1 - new branch
    [10MHzRefOsc_2V1.brd, 10MHzRefOsc_2V1.sch, 10MHzRefOsc_2V2.brd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]
2017-03-20 HW_V2.1.1 - dropping unneeded things
    [10MHzRefOsc_2V2.brd, 10MHzRefOsc_2V2.sch, 10MHzRefOsc_2V3.brd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]
2017-03-20 master - LCD_V1.1 merged
    [10MHzRefOsc_2V2.brd, 10MHzRefOsc_2V2.sch, 10MHzRefOsc_2V3.brd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]
2018-07-05 HW_V2.1.1 - GPS connector - fixed 5V to 3V3 in info block
    [10MHzRefOsc_2V1.sch]
2018-07-05 HW_V2.2.1 - GPS connector - fixed 5V to 3V3 in info block
    [10MHzRefOsc_2V2.sch]
2018-07-05 HW_V2.3.1 - GPS connector - fixed 5V to 3V3 in info block
    [RefOsc10MHz_2V3.sch]
